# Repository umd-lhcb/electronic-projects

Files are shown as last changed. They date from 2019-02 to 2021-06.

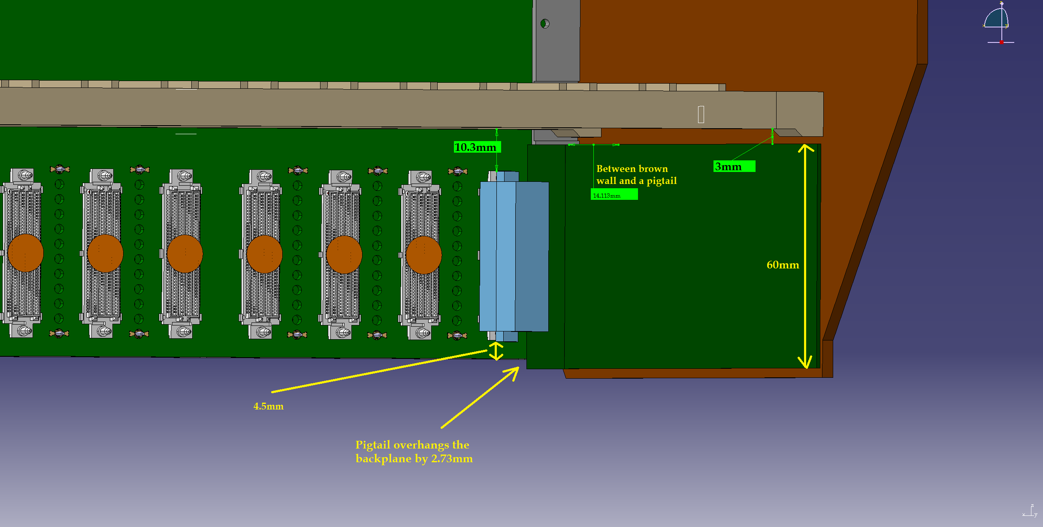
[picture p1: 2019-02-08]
backplane/mechanics/19-02-08_stackup_mech_constraints_cern/mech_constraints_backplane/BB_lower_DCB_GuideDetail__870a.png

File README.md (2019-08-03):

# electronic-projects
Repository with the project, gerber, and pdf files for the boards to
be delivered by UMD for the UT upgrade: `backplane`, `dcb`, and `lvr`.

Electronic boards designed by UMD for UT boards testing purposes, such as
`comet` and `gbtx_db`  are also included.

Latest pdf schematics of each project are also provided.

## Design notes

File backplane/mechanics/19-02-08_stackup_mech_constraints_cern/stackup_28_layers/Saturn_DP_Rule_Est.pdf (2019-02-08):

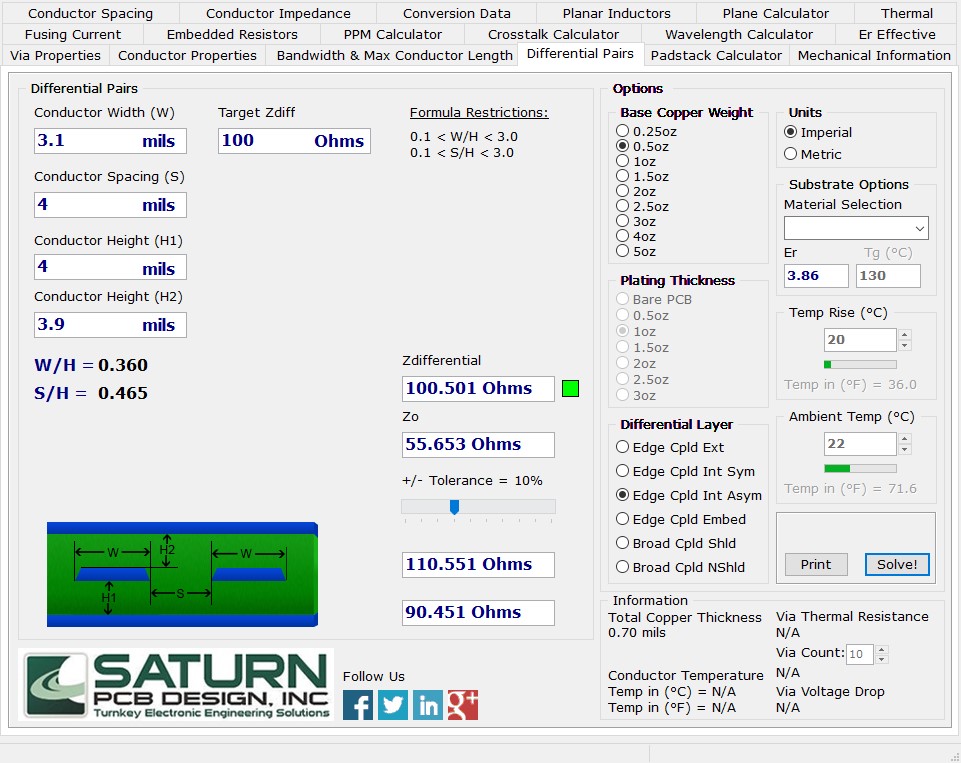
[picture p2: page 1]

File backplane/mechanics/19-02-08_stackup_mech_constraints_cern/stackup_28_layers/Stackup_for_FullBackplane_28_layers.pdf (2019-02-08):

| | | PathFinder-Alternate-28 layer
~ MILS | Cu layer
2 | 1 | Cu | | TOP plane--BROKEN Cu FILL
3.9 PP
0.7 | 2 | Cu | | DP signals-100 Ohms
4 CORE
0.7 | 3 | Cu | | plane
3.9 PP
0.7 | 4 | Cu | | DP signals-100 Ohms
4 CORE
0.7 | 5 | Cu | | plane
3.9 PP
0.7 | 6 | Cu | | DP signals-100 Ohms
4 CORE
0.7 | 7 | Cu | | plane
3.9 PP
0.7 | 8 | Cu | | DP signals-100 Ohms
4 CORE
0.7 | 9 | Cu | | plane
3.9 PP
0.7 | 10 | Cu | | DP signals-100 Ohms
4 CORE
0.7 | 11 | Cu | | plane
3.9 PP
0.7 | 12 | Cu | | SE.DP & NON-DP signal | Routing Constaints needed to control crosstalk & Tline discontinuities
4 CORE
0.7 | 13 | Cu | | SE.DP & NON-DP signal | Routing Constaints needed to control crosstalk & Tline discontinuities
3.9 PP
1.4 | 14 | Cu | 1OZ PWR- 1.2 & 1.5 | sub-divided power plane

### 2 CORE

1.4 | 15 | Cu | 1OZ PWR- 1.2 & 23.5 | sub-divided power plane
3.9 PP
0.7 | 16 | Cu | SE.DP & NON-DP signal | Routing Constaints needed to control crosstalk & Tline discontinuities
4 CORE
0.7 | 17 | Cu | SE.DP & NON-DP signal | Routing Constaints needed to control crosstalk & Tline discontinuities
3.9 PP
0.7 | 18 | Cu | plane
4 CORE
0.7 | 19 | Cu | DP signals-100 Ohms
3.9 PP
0.7 | 20 | Cu | plane
4 CORE
0.7 | 21 | Cu | DP signals-100 Ohms
3.9 PP
0.7 | 22 | Cu | plane
4 CORE
0.7 | 23 | Cu | DP signals-100 Ohms
3.9 PP
0.7 | 24 | Cu | plane
4 CORE
0.7 | 25 | Cu | DP signals-100 Ohms
3.9 PP
0.7 | 26 | Cu | plane
4 CORE
0.7 | 27 | Cu | DP signals-100 Ohms
3.9 PP
2 | 28 | Cu | BOT plane--BROKEN Cu FILL

128.2 mils total

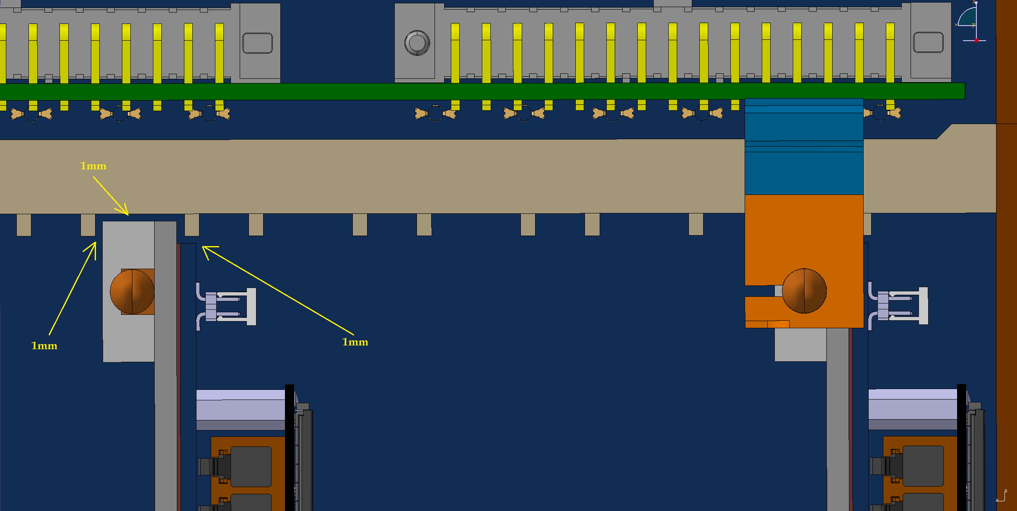
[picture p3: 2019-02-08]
backplane/mechanics/19-02-08_stackup_mech_constraints_cern/mech_constraints_backplane/BP_DCB_Slot_Detail__966.png

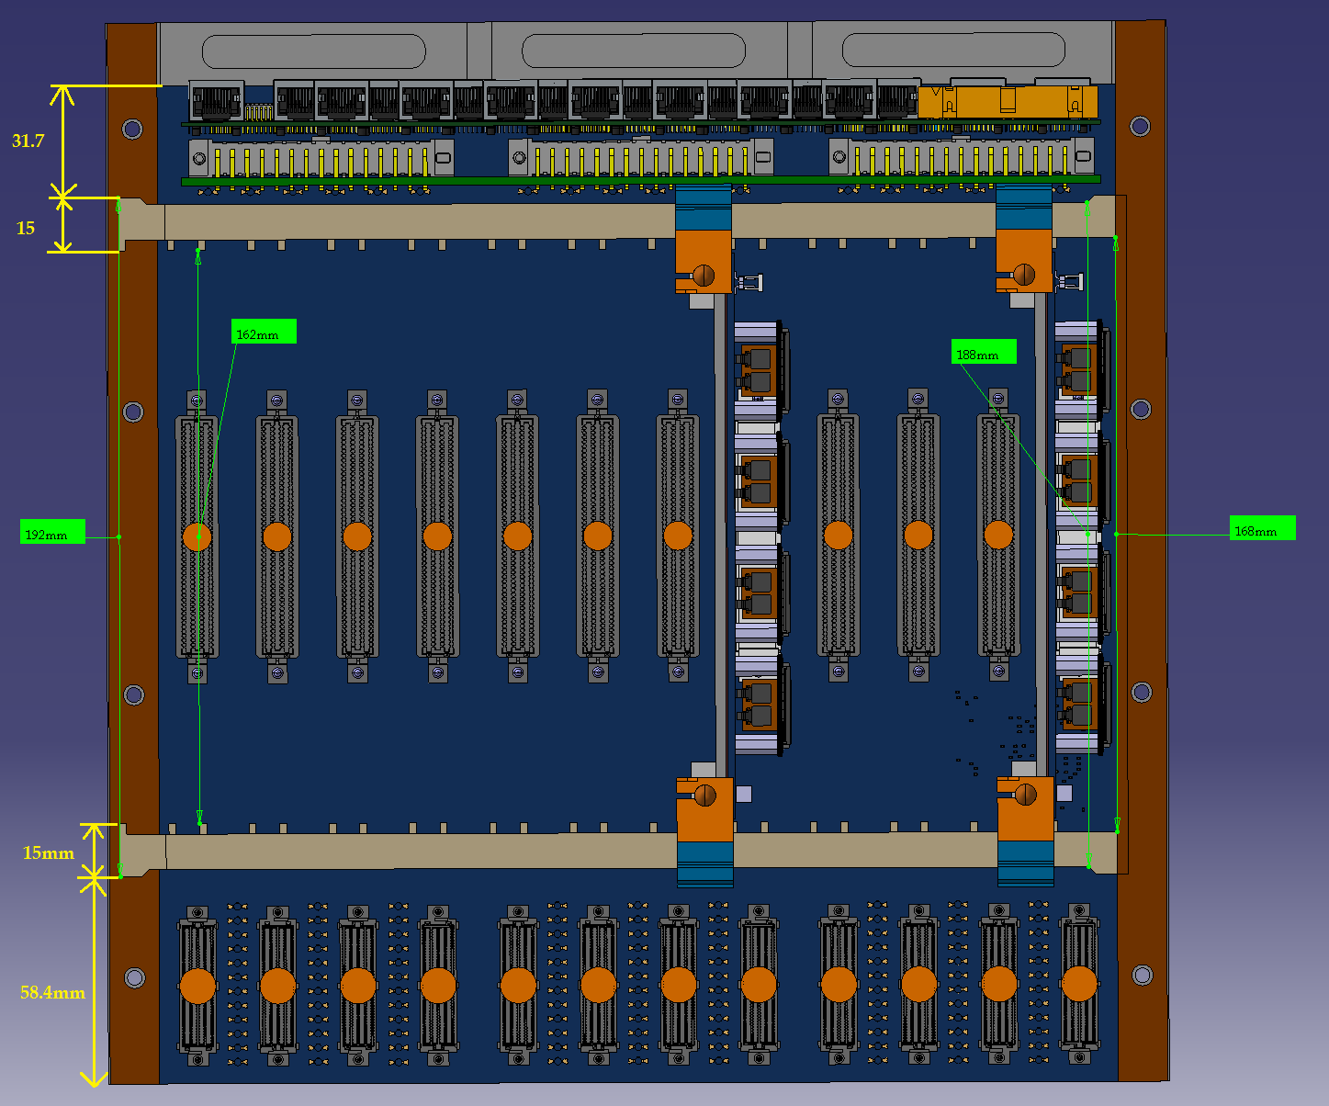
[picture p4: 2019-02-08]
backplane/mechanics/19-02-08_stackup_mech_constraints_cern/mech_constraints_backplane/BP_Conn_Location_Details__964.png

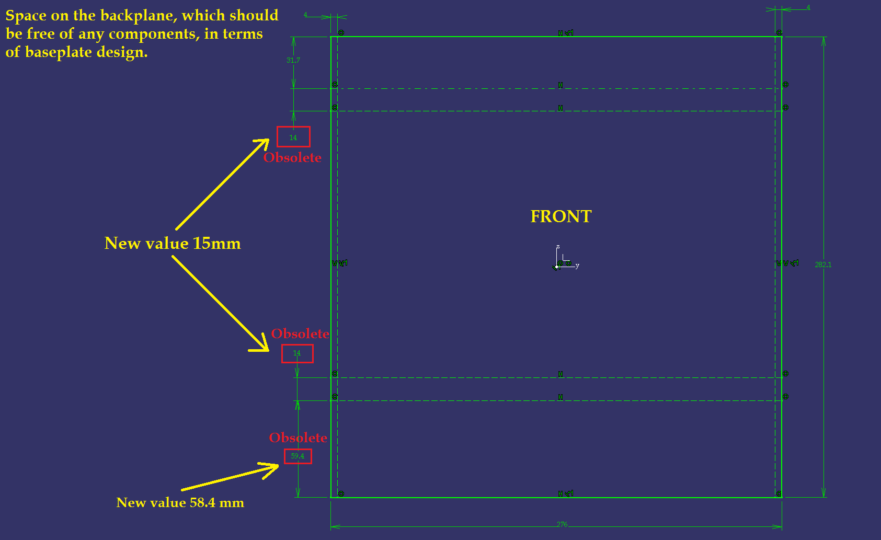
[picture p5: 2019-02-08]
backplane/mechanics/19-02-08_stackup_mech_constraints_cern/mech_constraints_backplane/BB_KeepOut__836c.png

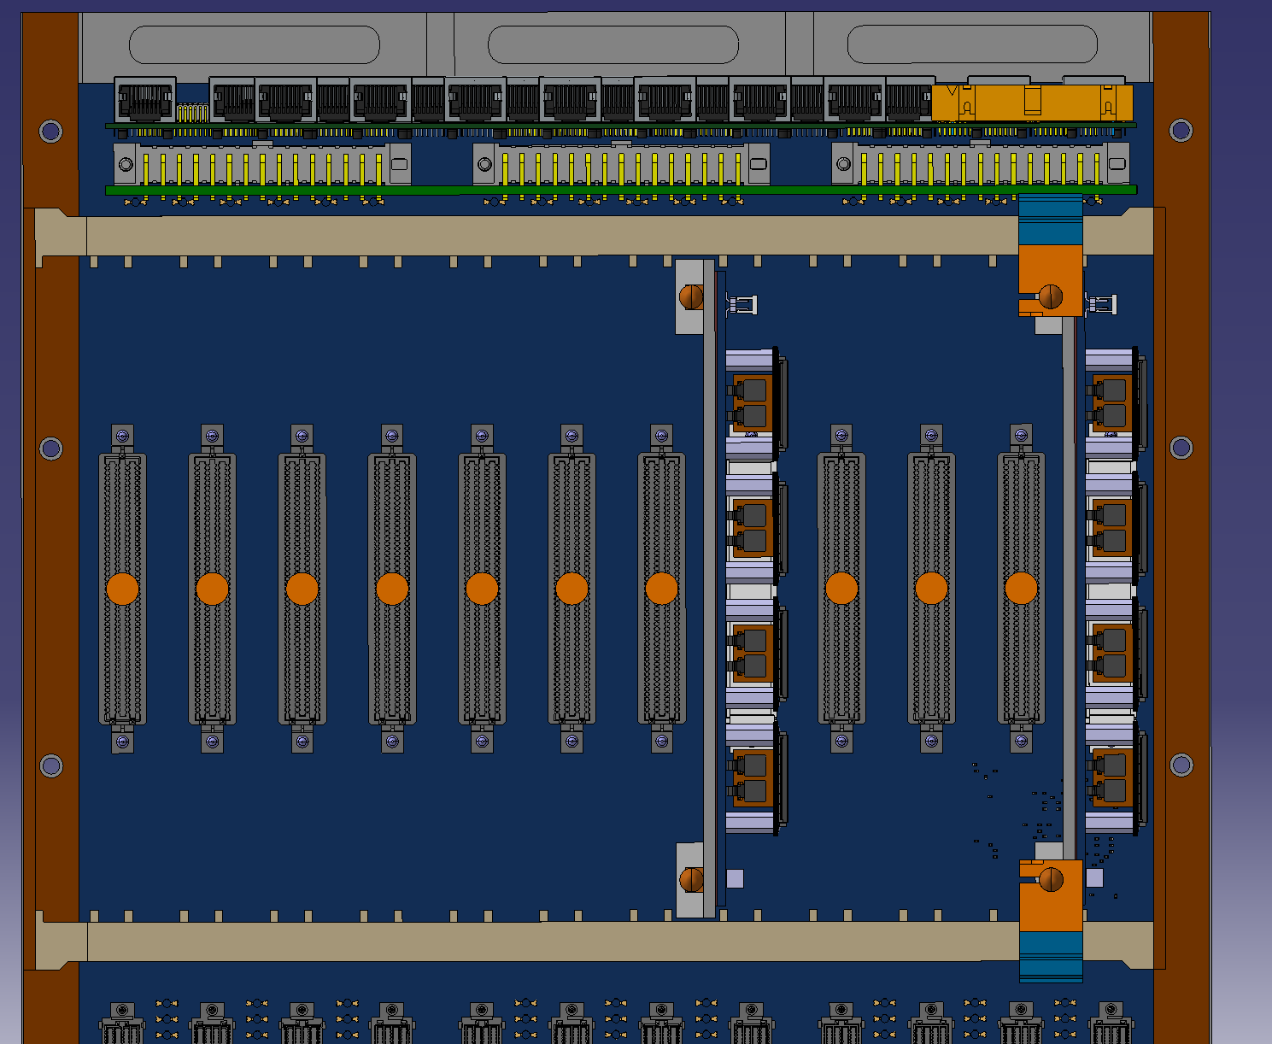
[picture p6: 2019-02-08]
backplane/mechanics/19-02-08_stackup_mech_constraints_cern/mech_constraints_backplane/BP_OverView__965.png

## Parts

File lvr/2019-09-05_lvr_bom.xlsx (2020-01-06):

Line ID | Designator | Quantity | Manufacturer | P/N | Description | Package | # Boards | Ext. Quant.
1 | C1 | 1 | Kemet | C0805C102K5RACTU | Non-polarised ceramic capacitor, X7R, 1.0nF, 50V, +/-10% tol | SMD 0805 | 295 | 325
2 | C2A, C2B, C2C, C2D, C2E, C2F, C2G, C2H, C100 | 9 | Yaego | CC0805JRNPO9BN100 | Non-polarised ceramic capacitor, NPO, 10pF, 50V, +/-5% tol | SMD 0805 | 295 | 2921
3 | C3A, C3B, C3C, C3D, C4, C5, C6, C7, C8, C9, C10, C11, C12, C15, C16, C27, C30, C34A, C34B, C34C, C34D, C34E, C34F, C34G, C34H, C47, C49, C58, C59, C60, C61, C62, C63, C66, C67, C69, C70, C72, C87, C88, C92, C95, C101, C141, C142, C143 | 46 | Murata | GCM155R71H103KA55D | Non-polarised ceramic capacitor, X7R, 0.01uF, 50V, +/-10% tol | SMD 0402 | 295 | 16963
4 | C13, C14, C21, C23, C38A, C38B, C38C, C38D, C38E, C38F, C38G, C38H, C39, C41A, C41B, C41C, C41D, C41E, C41F, C41G, C41H, C42A, C42B, C42C, C42D, C42E, C42F, C42G, C42H, C46, C64, C86, C93, C96, C98, C113, C114, C119, C122, C123A, C123B, C123C, C123D, C123E, C123F, C123G, C123H, C125A, C125B, C125C, C125D, C125E, C125F, C125G, C125H, C127A, C127B, C127C, C127D, C127E, C127F, C127G, C127H, C130, C132, C133, C134, C135, C144, C145 | 70 | Murata | GCM21BR71C475KA73K | Non-polarised ceramic capacitor, X7R, 4.7uF, 16V, +/-10% tol | SMD 0805 | 295 | 22715
5 | C17, C24A, C24B, C24C, C24D, C24E, C24F, C24G, C24H, C103, C147 | 11 | Kemet | C0805C105K4RACAUTO | Non-polarised ceramic capacitor, X7R, 1.0uF, 16V, +/-10% tol | SMD 0805 | 295 | 3570
6 | C18, C20, C22, C25A, C25B, C25C, C25D, C25E, C25F, C25G, C25H, C148 | 12 | AVX | TCJA106M016R0200 | Conductive Polymer Tantalum Capacitor, 16V, 200mOhm ESR, 10uF, +/-20% tol | SMD 1206 | 295 | 3894
7 | C19, C26, C28, C48, C31A, C31B, C31C, C31D, C31E, C31F, C31G, C31H, C52, C55, C65, C68, C71, C73, C89, C90, C97, C99, C102, C131, C146 | 25 | Yaego | CC0402KRX7R7BB104 | Non-polarised ceramic capacitor, X7R, 0.1uF, 16V, +/-10% tol | SMD 0402 | 295 | 9219
8 | C29, C33, C35 | 3 | AVX | 0402YC470KAT2A | Non-polarised ceramic capacitor, X7R, 47pF, 16V, +/-10% tol | SMD 0402 | 295 | 1107
9 | C32A, C32B, C32C, C32D, C32E, C32F, C32G, C32H, C80, C81, C82, C83, C84, C85, C104, C105 | 16 | AVX | TCJD227M016R0050 | Conductive Polymer Tantalum Capacitor, 16V, 50mOhm ESR, 220uF, +/-20% tol | SMD 2917 | 295 | 5192
10 | C56, C57, C74, C75, C76, C77, C78, C79, C126, C139, C140 | 11 | AVX | TCJD227M010R0050 | Conductive Polymer Tantalum Capacitor, 10V, 50mOhm ESR, 220uF, +/-20% tol | SMD 2917 | 295 | 3570
11 | C91, C94 | 2 | Yaego | CC0603KRX7R7BB334 | Non-polarised ceramic capacitor, X7R, 0.33uF, 16V, +/-10% tol | SMD 0603 | 295 | 620
12 | d8, d9, d10, d11, d12, d13, d14, d15, d16, d17, d19, D5, D6, D7 | 14 | On Semi | MBRS360BT3G | DIODE SCHOTTKY 60V 3A SMB | DO-214AA, SMB | 295 | 4337
13 | D2, D3A, D3B, D3C, D3D, D3E, D3F, D3G, D3H, D4A, D4B, D4C, D4D, D4E, D4F, D4G, D4H, D23, D24, D25 | 20 | Vishay Semi | VS-50WQ06FN-M3 | DIODE SCHOTTKY 60V 5.5A, TO-252AA | DO-252AA | 295 | 6490
14 | D18, D20A, D20B, D20C, D20D, D21A, D21B, D21C, D21D, D22A, D22B, D22C, D22D | 13 | On Semi | 1N4148WS | Diode general purpose, 75V, 150 ma | SOD323F | 295 | 4027
15 | IC1A, IC1B, IC1C, IC1D, IC1E, IC1F, IC1G, IC1H, IC2, IC6 | 10 | Maxim IC | MAX4238AUT+T | Op amp, rail-to-rail, 1MHz GBW, unit gain stable | SOT23-6 | 295 | 152
16 | IC4, IC7A, IC7B, IC7C, IC7D, IC7E, IC7F, IC7G, IC7H, IC15 | 10 | CERN | LHC4913PDU | 3A Positive Low Drop Adjustable Voltage Regulator With Inhibit Function | ST_POWERSO-20-SLUG-Up | 295 | 3098
17 | IC11 | 1 | Microsemi | A3PN250-VQG100 | ProASIC Nano FPGA, 250K gates, flash-based | 100-VQFP | 295 | 310
18 | IC12 | 1 | Maxim IC | MAX3491ESD+ | Differential Transceiver RS485/422, 10MBPS | 14SOIC | 295 | 310
19 | J1, J7, J8, J22 | 4 | Samtec | TMM-103-01-L-D-SM-P | Low profile SMT header, 2x3, 2mm pitch, 10um gold, Pick-N-Place Pad | SMD | 295 | 1239
20 | J4A, J4B, J4C, J4D, J4E, J4F, J4G, J4H | 8 | Samtec | SFM-115-02-L-D-A | Vertical 1.27mm pitch 2x15 connector, 10u-inch gold finish | SMD | 295 | 2478
21 | J5, J6, J10, J16 | 4 | Molex | 095540-6880 | RJ45 connector, shielded, right angle | SMD | 295 | 1239
22 | J11 | 1 | Samtec | TSM-115-01-S-DV-A-P | Contacts 2x15, Vertical, Surface Mount, Alignment Pins | SMD | 295 | 310
23 | J12, J13, J14 | 3 | Samtec | MPT-08-01-03-L-RA-SD | 30A power connector, 8 terminals, 10 u-inch gold finish | SMD | 295 | 930
24 | J15, J19, J20, J21 | 4 | Keystone | 4966 | Terminal lug, .250" X 0.032", right angle | Thru-hole | 295 | #N/A
25 | J17 | 1 | Samtec | HTST-105-04-G-D-RA | Shrouded header, 2x5 contacts, right angle, 10 u-inch gold finish | Thru-hole | 295 | #N/A
26 | J18 | 1 | Samtec | TSM-125-01-S-DV-A-P | vertical header pins, 2x25, 0.230 inch post height for mate with BCS | SMD | 295 | 310
27 | L1 | 1 | Murata | LQW31HN23NJ03L | 23nH Unshielded Wirewound Inductor, 590mA @ 46 mOhm Max | SMD 1206 / 3216 Metric | 295 | 325
28 | L2, L3 | 2 | Wurth | 742792022 | FERRITE BEAD 220 OHM @ 100 MHz | SMD 0805 | 295 | 649
29 | LD1, LD2, LD3, LD4, LD5, LD6, LD7 | 7 | Broadcom LTD (Avago) | HSME-C120 | LED GREEN CLEAR CHIP SMD R/A | SMD | 295 | 2272
30 | OSC1 | 1 | IQD Frq Products | LFSPXO018042REEL | Oscillator IQD_CFPS-73 (40MHz), 50 PPM freq Stab, 3.3V | 4-SMD | 295 | 310
31 | P1 | 1 | Bourns | 3223W-1-103E | Trimmer Pot, 11-turn, top Adj, 10K | SMD J-Lead | 295 | 310
32 | P2, P3, P4 | 3 | Bourns | 3223W-1-102E | Trimmer Pot, 11-turn, top Adj, 1K | SMD J-Lead | 295 | 930
33 | P5 | 1 | Bourns | 3223W-1-202E | Trimmer Pot, 11-turn, top Adj, 2K | SMD J-Lead | 295 | 310
34 | Q3A, Q3B, Q3C, Q3D | 4 | Diodes Inc | DMMT3906W-7-F | 40V MATCHED PAIR PNP SMALL SIGNAL TRANSISTOR | SMD SOT363 | 295 | 1298
35 | Q4, Q8A, Q8B, Q8C, Q8D, Q8E, Q8F, Q8G, Q8H | 9 | Diodes Inc | ZXT953K | Bipolar (BJT) Transistor PNP 100V 5A | SMD TO252 (DPAK) | 295 | 2788
36 | Q5, Q9A, Q9B, Q9C, Q9D, Q9E, Q9F, Q9G, Q9H | 9 | ON Semiconductor | PZT3904T1G | Bipolar (BJT) Transistor NPN 40V, 0.2A | SMD SOT-223 | 295 | 2788
37 | R1, R2, R3, R4, R94A, R94B, R94C, R94D, R94E, R94F, R94G, R94H, R102, R184, R212, R231A, R231B, R231C, R231D | 19 | Yageo | RC0402FR-0710KL | Resistor, 10K Ohms, +/-1% tol, 0.063 W | SMD 0402 | 295 | 7007
38 | R5, R44 | 2 | Vishay Dale | CRCW04021K00DHEDP | Resistor 1k Ohms, +/-1% tol, 0.063W, | SMD 0402 | 295 | 738
39 | R6A, R6B, R6C, R6D, R54, R62, R81A, R81B, R81C, R81D, R81E, R81F, R81G, R81H, R119, R127, R199 | 17 | Stackpole | RMCF0402FT2K00 | Resistor 2k Ohms, +/-1% tol, 0.063W, | SMD 0402 | 295 | 6269
40 | R125 | 0 | DNI | DNI | Do Not Install | SMD 0402 | 295 | 20
41 | R7, R8, R9, R36, R37, R50, R60, R71, R75, R77, R89, R99, R100, R117, R122, R123, R128, R129A, R129B, R129C, R129D, R130A, R130B, R130C, R130D, R131, R132, R177, R178, R180 | 30 | Yageo | RC0402FR-0733RL | Resistor, 33 Ohms, +/-1% tol, 0.063 W | SMD 0402 | 295 | 11063
42 | R10, R61A, R61B, R61C, R61D, R61E, R61F, R61G, R61H | 9 | vishay Dale | CRCW08055R10FKEAHP | Resistor 5.1 Ohms, +/-1% tol, 0.5W, pulse withstanding | SMD 0805 | 295 | 2921
43 | R11, R64, R65, R66, R88, R101, R107, R108, R109, R110, R111, R112, R115, R188 | 14 | TT Electronics (Welwyn) | LRC-LR2010LF-01-R500-F | Resistor 0.500 Ohms, +/-1% tol, 1.0W, | SMD 2010 | 295 | 4543
44 | R179, R209, R211 | 3 | Vishay Dale | CRCW0402100RFKED | Resistor 100 Ohms, +/-1% tol, 0.063W, | SMD 0402 | 295 | 1107
44 | R12, R13, R15, R16, R18, R19, R21, R22, R24, R25, R27, R28, R30, R31, R33, R34 | 16 | Stackpole | RMCF0402FT249R | Resistor 249 Ohms, +/-1% tol, 0.063W, | SMD 0402 | 295 | 5900
45 | R14, R17, R20, R23, R26, R29, R32, R35 | 8 | TT Electronics (Welwyn) | LRC-LRF2010LF-01-R020-F | Resistor 0.020 Ohms, +/-1% tol, 1.0W, current sense | SMD 2010 | 295 | 2596
46 | R38, R124 | 2 | Bourns | CRM0805-FX-R510ELF | Resistor 510 mOhms, +/-1%, 0.25W current sense | SMD 0805 | 295 | 649
47 | R40, R90A, R90B, R90C, R90D, R90E, R90F, R90G, R90H | 9 | Stackpole | CSRN2512FKR250 | Resistor 250 mOhms, +/-1%, 2W current sense | SMD 2512 | 295 | 2921
48 | R41, R92A, R92B, R92C, R92D, R92E, R92F, R92G, R92H | 9 | Yageo | RC0805FR-0749R9L | Resistor 49.9 Ohms, +/-1%, 0.125W | SMD 0805 | 295 | 2921
49 | R42 | 1 | Yageo | RC0402FR-07470RL | Resistor, 470 Ohms, +/-1% tol, 0.063 W | SMD 0402 | 295 | 369
50 | R43, R46, R48, R49, R58, R68, R74, R79, R84, R98A, R98B, R98C, R98D, R98E, R98F, R98G, R98H | 17 | Yageo | RC0805FR-07220RL | Resistor, 220 Ohms, +/-1% tol, 0.125 W | SMD 0805 | 295 | 5517
51 | R45, R70 | 2 | Yageo | RC0402FR-071K43L | Resistor 1k43 Ohms, +/-1% tol, 0.063W, | SMD 0402 | 295 | 738
52 | R47 | 0 | DNI | DNI | Do Not Install | SMD 0805 | 295 | 10
53 | R51, R76, R226A, R226B, R226C, R226D, R120, R126, R55A, R55B, R55C, R55D, R55E, R55F, R55G, R55H, R59A, R59B, R59C, R59D, R59E, R59F, R59G, R59H | 24 | Yageo | RC0402FR-071K2L | Resistor 1k2 Ohms, +/-1% tol, 0.063W, | SMD 0402 | 295 | 8850
54 | R52, R83 | 2 | Yageo | RC0402FR-07750RL | Resistor 750 Ohms, +/-1% tol, 0.063W, | SMD 0402 | 295 | 738
55 | R53 | 1 | Vishay Dale | CRCW08050000Z0EAHP | Resistor 0.0 Ohms Shunt Jumper | SMD 0805 | 295 | 325
56 | R56, R85 | 2 | Yageo | RC0402FR-076K2L | Resistor 6.2K Ohms, +/-1% tol, 0.063W, | SMD 0402 | 295 | 738
57 | R57, R82 | 0 | DNI | DNI | Do Not Install | SMD 0805 | 295 | 10
58 | R63A, R63B, R63C, R63D, R63E, R63F, R63G, R63H, R181, R182, R183 | 11 | Vishay Dale | CRCW0402510RFKED‎C | Resistor 510 Ohms, +/-1% tol, 0.063W, | SMD 0402 | 295 | 4057
59 | R67, R72 | 2 | Yageo | RC0402FR-07140RL | Resistor 140 Ohms, +/-1% tol, 0.063W, | SMD 0402 | 295 | 738
60 | R69, R113, R114, R210 | 4 | Yageo | RC0402FR-0749R9L | Resistor 49.9 Ohms, +/-1% tol, 0.063W, | SMD 0402 | 295 | 1475
61 | R73A, R73B, R73C, R73D, R73E, R73F, R73G, R73H | 8 | Stackpole | CSRN2010FK50L0 | Resistor, 50 mOhms, +/-1%, 1W | SMD 2010 | 295 | 2596
62 | R39, R78A, R78B, R78C, R78D, R78E, R78F, R78G, R78H | 9 | Bourns | CRM2512-FX-R100ELF | Resistor 100 mOhms, +/-1%, 2W current sense | SMD 2512 | 295 | 2921
63 | R80A, R80B, R80C, R80D, R208, R230A, R230B, R230C, R230D | 9 | yageo | RC0402FR-07200RL | Resistor 200 Ohms, +/-1% tol, 0.063W, | SMD 0402 | 295 | 3319
64 | R86 | 1 | yageo | RC0402FR-07249RL | Resistor 249 Ohms, +/-1% tol, 0.063W, | SMD 0402 | 295 | 369
65 | R87 | 1 | Stackpole | RMCF0402FT1K10 | Resistor1.1K Ohms, +/-1% tol, 0.063W, | SMD 0402 | 295 | 369
66 | R91A, R91B, R91C, R91D, R91E, R91F, R91G, R91H | 8 | Stackpole | CSRN2010FKR150 | Resistor 0.150 Ohms, +/-1% tol, 1.0W, | SMD 2010 | 295 | 2596
67 | R93A, R93B, R93C, R93D, R93E, R93F, R93G, R93H | 8 | yageo | RC0805FR-07470RL | Resistor 470 Ohms, +/-1%, 0.125W | SMD 0805 | 295 | 2596
68 | R95, R97 | 2 | yageo | RC0805FR-07360RL | Resistor 360 Ohms, +/-1%, 0.125W | SMD 0805 | 295 | 649
69 | R96 | 1 | yageo | RC0805FR-07121RL | Resistor 121 Ohms, +/-1%, 0.125W | SMD 0805 | 295 | 325
70 | R103, R104, R105, R106, R121 | 5 | yageo | RC0603FR-07360RL | Resistor 360 Ohms, +/-1%, 0.1W | SMD 0603 | 295 | 1697
71 | R116, R227A, R227B, R227C, R227D | 5 | Panasonic | ERJ-2RKF4871X | Resistor 4.87K Ohms, +/-1%, 0.1W | SMD 0402 | 295 | 1844
72 | R118 | 1 | Yageo | RC0805FR-076K2L | Resistor 6.2K Ohms, +/-1%, 0.125W | SMD 0805 | 295 | 325
73 | R161A, R161B, R161C, R161D, R161E, R161F, R161G, R161H, R203A, R203B, R203C, R203D, R203E, R203F, R203G, R203H | 16 | Yageo | RC0402FR-0751KL | Resistor 51K Ohms, +/-1% tol, 0.063W, | SMD 0402 | 295 | 5900
74 | R207, R229A, R229B, R229C, R229D | 5 | Yageo | RC0402FR-07390RL | Resistor 390 Ohms, +/-1% tol, 0.063W, | SMD 0402 | 295 | 1844
75 | R225A, R225B, R225C, R225D | 4 | Yageo | RC0402FR-07560RL | Resistor 560 Ohms, +/-1% tol, 0.063W, | SMD 0402 | 295 | 1475
76 | R228A, R228B, R228C, R228D | 4 | Yageo | RC0402FR-07820RL | Resistor 820 Ohms, +/-1% tol, 0.063W, | SMD 0402 | 295 | 1475
77 | RN1A, RN1B, RN1C, RN1D, RN1E, RN1F, RN1G, RN1H, RN3A, RN3B, RN3C, RN3D, RN3E, RN3F, RN3G, RN3H | 16 | Vishay Beyschlag | ACASA2001X2001P100 | WHERE 'X'=S, 1, T, or U (in this order of preference). Resistor network, 2k Ohm x4, TC and tol. Specified by 'X' | SMD 0612 | 295 | 5192
78 | RN2A, RN2B, RN2C, RN2D, RN2E, RN2F, RN2G, RN2H | 8 | Vishay Beyschlag | ACASA5002X5002P100 | WHERE 'X'=S, 1, T, or U (in this order of preference). Resistor network, 51k Ohm x4, TC and tol. Specified by 'X' | SMD 0612 | 295 | 2596
79 | RN6 | 1 | Vishay Beyschlag | ACASA1001X1001P100 | WHERE 'X'=S, 1, T, or U (in this order of preference). Resistor network, 1k Ohm x4, TC and tol. Specified by 'X' | SMD 0612 | 295 | 325
80 | RN7 | 1 | Vishay Beyschlag | ACASA1000X1000P100 | WHERE 'X'=S, 1, T, or U (in this order of preference). Resistor network, 100 Ohm x4, TC and tol. Specified by 'X' | SMD 0612 | 295 | 325
81 | RN8 | 1 | Vishay Beyschlag | ACASA1002X1002P100 | WHERE 'X'=S, 1, T, or U (in this order of preference). Resistor network, 10K Ohm x4, TC and tol. Specified by 'X' | SMD 0612 | 295 | 325
82 | RN9, RN10, RN17, RN18, RN19, RN20, RN21, RN22, RN23, RN24 | 10 | Panasonic | EXB-N8V103JX | 4 Resistor Network/Array, 10k Ohm Isolated, ±5%, 31mW Power Per Element, ±200ppm/°C , Concave, Long Side Terminals | SMD 0804 | 295 | 3393
83 | RN11, RN12, RN13, RN14, RN15, RN16, RN25, RN26, RN27, RN28 | 10 | Panasonic | EXB-N8V330JX | 4 Resistor Network/Array, 33 Ohm Isolated, ±5%, 31mW Power Per Element, ±200ppm/°C , Concave, Long Side Terminals | SMD 0804 | 295 | 3393
84 | RT1, RT2, RT3 | 3 | TE Connectivity, Meas't Specialities | NB-PTCO-330 | 1 kOhms RTD, ±0.23%, -50°C ~ 150°C, 1206 (3216 Metric) | SMD 1206 | 295 | 974
85 | RT4A, RT4B, RT4C, RT4D | 4 | TDK (EPCOS) | B57471V2472J062 | 4.7K thermistor, NTC, 5% tol | SMD 0805 | 295 | 1239
86 | SW1, SW2, SW3, SW4, SW5, SW6A, SW6B, SW6C, SW6D | 9 | Nidec Copal Electronics | CHS-04TA | Dip Switch SPST 4 Position Surface Mount Slide (Standard) Actuator 100mA 6VDC | SMD J-lead | 295 | 2921
87 | T1A, T1B, T1C, T1D, T1E, T1F, T1G, T1H, T2A, T2B, T2C, T2D, T3 | 13 | ON Semiconductor | MMBT3904WT1G | Bipolar (BJT) Transistor NPN 40V 200mA 300MHz 150mW | SMD SC-70-3 (SOT323) | 295 | 4027
88 | TP1, TP2A, TP2B, TP2C, TP2D, TP2E, TP2F, TP2G, TP2H, TP3, TP4, TP5A, TP5B, TP5C, TP5D, TP5E, TP5F, TP5G, TP5H, TP6, TP7, TP8, TP9, TP10, TP11A, TP11B, TP11C, TP11D, TP11E, TP11F, TP11G, TP11H, TP12, TP13, TP14, TP15, TP16, TP17, TP18A, TP18B, TP18C, TP18D, TP19A, TP19B, TP19C, TP19D, TP20, TP21 | 48 | Tyco | RCT-0C | PCB test point | SMD
Misc HW
1 | WL1, WL2 | 2
2 | M3 retention hardware for J12, J13, and J14 | 3 conns
3 | 2mm Shunt Jumpers |  | Samtec | 2SN–BK–G | 2mm pitch shunt for use with TMM series, gold sockets
4 | P4A, P4B, P4C, P4D, P4E, P4F, P4G, P4H |  | UMD | CCM-TypeID | Config Control Mezzanine
 |  |  |  | Component | % extra | min extra
 |  |  |  | SMD 0201 | 0.5 | 50
 |  |  |  | SMD 0402 | 0.25 | 20
 |  |  |  | SMD 0603 | 0.15 | 20
 |  |  |  | SMD 0804 | 0.15 | 20
 |  | 754 |  | SMD 0805 | 0.1 | 10
 |  |  |  | SMD 1206 | 0.1 | 5
 |  |  |  | SMD 0612 | 0.1 | 5
 |  |  |  | SMD 2010 | 0.1 | 5
 |  |  |  | SMD 2512 | 0.1 | 5
 |  |  |  | SMD 2917 | 0.1 | 5
 |  |  |  | Other Passive | 0.1 | 5
 |  |  |  | Thru-Hole | 0.02 | 1

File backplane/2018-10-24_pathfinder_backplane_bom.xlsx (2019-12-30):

Line Item | Designator | LibRef | Qty | Chk | PartNumID | Manufacturer | P/N | Description | Package
1 | C49, C50, C51, C52, C53, C54, C55, C56, C57, C58, C59, C60, C61, C62, C63, C64, C65, C66, C67, C68, C69, C70, C71, C72, C73, C74, C75, C76, C77, C78, C79, C80, C81, C82, C83, C84, C85, C86, C87, C88, C89, C90, C91, C92, C93, C94, C95, C96, C97, C98, C99, C100, C101, C102, C103, C212, C213, C214, C215, C216, C217, C218, C219, C220, C221, C222, C223, C224, C225, C226, C227, C228, C229, C230, C231, C232, C233, C234, C235, C236, C237, C238, C239, C240, C241, C242, C243 |  | 87 |  | cap10 | Samsung Electro-Mechanics | CL05B473KO5VPNC | Non-polarised ceramic capacitor, X7R, 0.047uF, 16V, +/-10% tol | SMD 0402
2 | C1, C2, C3, C4, C5, C6, C7, C8, C9, C10, C11, C12, C13, C14, C15, C16, C17, C18, C19, C20, C21, C22, C23, C24, C25, C26, C27, C28, C29, C30, C31, C32, C33, C34, C35, C36, C37, C38, C39, C40, C41, C42, C43, C44, C45, C46, C47, C48 |  | 48 |  | cap11 | Murata | GCM155R71E103KA37D | Non-polarised ceramic capacitor, X7R, 0.01uF, 25V, +/-10% tol | SMD 0402
3 | C104, C105, C106, C107, C108, C109, C110, C111, C112, C113, C114, C115, C116, C117, C118, C119, C120, C121, C122, C123, C124, C125, C126, C127, C128, C129, C130, C131, C132, C133, C134, C135, C136, C137, C138, C139, C140, C141, C142, C143, C144, C145, C146, C147, C148, C149, C150, C151, C152, C153, C154, C155, C156, C157, C158, C159, C160, C161, C162, C163, C164, C165, C166, C167, C168, C169, C170, C171, C172, C173, C174, C175, C176, C177, C178, C179, C180, C181, C182, C183, C184, C185, C186, C187, C188, C189, C190, C191, C192, C193, C194, C195, C196, C197, C198, C199, C200, C201, C202, C203, C204, C205, C206, C207, C208, C209, C210, C211 |  | 108 |  | cap2 | Murata | GRM155R71C104KA88 | Non-polarised ceramic capacitor, X7R, 0.1uF, 16V, +/-10% tol | SMD 0402
4 | COMET_A_J1, COMET_A_J2, COMET_B_J1, COMET_B_J2 |  | 4 |  | conn20 | Samtec | ERF8-050-05.0-S-DV-K-TR | Connector, 2 x50, -05.0 lead style, 30u gold, | SMD
5 | J38, J52 |  | 2 |  | conn3 | Samtec | TMM-110-01-L-D-SM-A-P | Low profile SMT header, 2x10, 2mm pitch, 10um gold, SMD alignment pin, Pick-N-Place Pad | SMD
6 | J39, J53 |  | 2 |  | conn4 | Samtec | TMM-112-01-L-D-SM-A-P | Low profile SMT header, 2x12, 2mm pitch, 10um gold, SMD alignment pin, Pick-N-Place Pad | SMD
7 | J1, J2, J3, J4, J5, J6, J7, J8, J9, J10, J11, J12, J13, J14, J15, J16, J17, J18, J19, J20, J21, J22, J23, J24, J25, J26, J27, J28, J29, J30, J31, J32, J33, J34, J35, J36, J37, J40, J41, J42, J43, J44, J45, J46, J47, J48, J49, J50, J51, J54, J55, J56, J57, J58, J59, J60 |  | 56 |  | conn1 | Hirose | U.FL-R-SMT-1(10) | U.FL, Ultra Miniature Coaxial Connector Receptacle, Male Pin 50 Ohm Surface Mount Solder | SMD
8 | JP0, JP1, JP2, JP3, JP4, JP5, JP6, JP7, JP8, JP9, JP10, JP11 |  | 12 |  | Conn15 | Samtec | SEAM8-40-S02.0-S-10-2-GP-K | SEARAY 0.8 mm pitch connector, 40x10, 2mm body height, Vertical, guide posts | SMD
9 | JD0, JD1, JD2, JD3, JD4, JD5, JD6, JD7, JD8, JD9, JD10, JD11 |  | 12 |  | Conn16 | Samtec | SEAM-50-02.0-S-08-2-A-GP-K-TR | SEARAY 1.25 mm pitch connector, 50x8, 2mm body height, Vertical, guide posts | SMD
10 | JPL0, JPL1, JPL2 |  | 3 |  | Conn17 | Samtec | IPBS-115-01-T-D-GP | PowerMate, 15 x 2 sockets, thru hole, Mate Tin, Double row, Guide posts | ThruHole
11 | JT0, JT1, JT2 |  | 3 |  | Conn18 | Samtec | SMS-150-02-L-D | Thru-hole micro sockets, 2x50, gold on contact + tin on tail, double row | ThruHole
12 | JS_JPU_ZERO_1 thru JS_JPU_ZERO_30 'JS_JPU_ONE_1 thru JS_JPU_ONE_30 'JS_JPU_TWO_1 thru JS_JPU_TWO_30 JS_PT_ZERO_ONE_1, JS_PT_ZERO_ONE_2, JS_PT_ONE_TWO_1, JS_PT_ONE_TWO_2, JS_PT_TWO_THREE_1, JS_PT_TWO_THREE_2, JS_JPL_ZERO_1 Thru JS_JPL_ZERO_6, JS_PT_FOUR_FIVE_1, JS_PT_FOUR_FIVE_2, JS_PT_FIVE_SIX_1, JS_PT_FIVE_SIX_2, JS_PT_SIX_SEVEN_1, JS_PT_SIX_SEVEN_2, JS_JPL_ONE_1 Thru JS_JPL_ONE_6, JS_PT_EIGHT_NINE_1, JS_PT_EIGHT_NINE_2, JS_PT_NINE_TEN_1, JS_PT_NINE_TEN_2, JS_PT_TEN_ELEVEN_1, JS_PT_TEN_ELEVEN_2, JS_JPL_TWO_1 Thru JS_JPL_TWO_6 |  | 126 |  | Conn19 | cap11+U8+U2+U3 | S9121-45R | Harwin Bottom entry sycamore socket, surface mount | SMD / Thru-hole
13 | R1, R2, R3, R4, R5, R6, R7, R8, R9, R10, R11, R12, R13, R14, R81, R87, R222, R223, R224, R225, R226, R227, R228, R229, R230, R231, R232, R233, R234, R235, R236, R237, R238, R239, R240, R241, R242, R243, R244, R245, R246, R247, R248, R249, R250, R251, R252, R253, R254, R255, R256, R257, R258, R259 |  | 54 |  | RES15 | Rohm Semiconductor | ESR10EZPJ5R6 | Resistor 5.6 Ohms, +/-5% tol, 0.4W, | SMD 0805
 | R15, R16, R17, R18, R19, R20, R21, R22, R23, R24, R25, R26, R27, R28, R29, R30, R31, R32, R33, R34, R35, R36, R37, R38, R39, R40, R41, R42, R43, R44, R45, R46, R47, R48, R49, R50, R51, R52, R53, R54, R55, R56, R57, R58, R59, R60, R61, R62, R63, R64, R65, R66, R67, R68, R69, R70, R71, R72, R73, R74, R75, R76, R77, R78, R79, R80, R82, R83, R84, R85, R86, R88, R89, R90, R91, R92, R93, R94, R95, R96, R97, R98, R99, R100, R101, R102, R103, R104, R105, R106, R107, R108, R109, R110, R111, R112, R113, R114, R115, R116, R117, R118, R119, R120, R121, R122, R123, R124, R125, R126, R127, R128, R129, R130, R131, R132, R133, R134, R135, R136, R137, R138, R139, R140, R141, R142, R143, R144, R145, R146, R147, R148, R149, R150, R151, R152, R153, R154, R155, R156, R157, R158, R159, R160, R161, R162, R163, R164, R165, R166, R167, R168, R169, R170, R171, R172, R173, R174, R175, R176, R177, R178, R179, R180, R181, R182, R183, R184, R185, R186, R187, R188, R189, R190, R191, R192, R193, R194, R195, R196, R197, R198, R199, R200, R201, R202, R203, R204, R205, R206, R207, R208, R209, R210, R211, R212, R213, R214, R215, R216, R217, R218, R219, R220, R221 |  | 205 |  |  |  |  | Do Not Install (100 Ohms, 040 package) | SMD 0402
14 | RT1 |  | 1 |  | RTD1 | TE Connectivity, Meas't Specialities | NB-PTCO-330 | 1 kOhms RTD, ±0.23%, -50°C ~ 150°C, 1206 (3216 Metric) | SMD 1206

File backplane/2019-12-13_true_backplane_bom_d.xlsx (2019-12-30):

Designator | MFG P/N | Package | Outline | PopulationType | DeviceType | Value | Quantity | Supplier | Description
FTG1, FTG2, FTG3, FTG4, FTG5, FTG6 | FIDUCIAL_TARGET_C100-200 | FIDUCIAL_TOP_C100-200 | - | MECH | DNI | - | 6 |  | Fiducial Target
C1, C2, C3, C4, C5, C6, C7, C9, C12, C14, C15, C20, C21, C22, C23, C24, C25, C26, C27, C34, C36, C37, C38, C39, C40, C41, C42, C44, C51, C52, C57, C60, C65, C68, C74, C75, C82, C84, C85, C87, C92, C99, C102, C104, C105, C106, C107, C108, C109, C110, C112, C115, C117, C118, C124, C129, C131, C132, C133, C134, C135, C136, C137, C138, C139, C140, C141, C142, C144, C145, C146, C151, C158, C160, C161, C162, C163, C164, C165, C166, C168, C170, C171, C177, C182, C184, C185, C186, C187, C188, C189, C190, C191, C192, C193, C194, C195, C196, C198, C199, C200, C202, C203, C207, C214, C217, C219, C220, C221, C222, C223, C224, C225, C227, C230, C232, C233, C239, C243, C244, C245, C246, C247, C248, C249, C250, C251, C252, C253, C254, C255, C256, C257, C258, C259, C263, C270, C272, C273, C274, C275, C276, C277, C278, C279, C280, C281, C282, C283, C284, C285, C286, C287, C288, C290, C297, C298, C302, C303, C304, C305, C306, C307, C308, C309, C310, C311, C312, C313, C314, C315, C316, C317, C318, C319, C320, C324, C327, C332, C335 | CC0402KRX7R7BB473 | CAPC1005X55N | 402 | SMD | SMD | 47nF | 180 | Customer will provide | Non-polarised capacitor
C8, C10, C11, C13, C16, C18, C19, C28, C32, C33, C35, C43, C45, C46, C47, C49, C53, C56, C58, C59, C61, C62, C63, C64, C66, C67, C69, C71, C73, C77, C79, C80, C81, C83, C86, C88, C89, C93, C94, C96, C98, C100, C101, C103, C111, C113, C114, C116, C120, C122, C123, C127, C128, C130, C143, C147, C148, C152, C153, C155, C157, C159, C167, C169, C173, C175, C176, C180, C181, C183, C197, C201, C204, C208, C209, C212, C213, C215, C216, C218, C226, C228, C229, C231, C235, C237, C238, C242, C260, C264, C265, C268, C269, C271, C289, C291, C293, C295, C296, C301, C321, C325, C326, C329, C331, C333, C334, C336 | EMK105B7104KV-F | CAPC1005X55N | 402 | SMD | SMD | 100nF | 108 | Customer will provide | Non-polarised capacitor
C17, C29, C30, C31, C48, C50, C54, C55, C70, C72, C76, C78, C90, C91, C95, C97, C119, C121, C125, C126, C149, C150, C154, C156, C172, C174, C178, C179, C205, C206, C210, C211, C234, C236, C240, C241, C261, C262, C266, C267, C292, C294, C299, C300, C322, C323, C328, C330 | TMK105B7103KV-F | CAPC1005X55N | 402 | SMD | SMD | 10nF | 48 | Customer will provide | Non-polarised capacitor
CxRB_1, CxRB_2, CxRB_3, CxRB_4, CxRB_5, CxRB_6, CxRB_7, CxRB_8, CxRB_9, CxRB_10, CxRB_11, CxRB_12, CxRB_13, CxRB_14, CxRB_15, CxRB_16, CxRB_17, CxRB_18, CxRB_19, CxRB_20, CxRB_21, CxRB_22, CxRB_23, CxRB_24, CxRB_25, CxRB_26, CxRB_27, CxRB_28, CxRB_29, CxRB_30, CxRB_31, CxRB_32, CxRB_33, CxRB_34, CxRB_35, CxRB_36 | RK73H1ETTP1000F | RESC1005X40N | 402 | SMD | SMD | 100 | 36 | Customer will provide | Resistor - 1%
R1, R2, R9, R10, R11, R12, R17, R18, R19, R20, R21, R23, R24, R29, R30, R33, R34, R35, R40, R45, R48, R49, R50, R55, R56, R59, R60, R61, R66, R67, R68, R74, R75, R78, R79, R80, R83, R86, R89, R90, R91, R96, R97, R100, R105, R106, R109, R115, R116, R117, R118, R123, R124, R125 | RC0805FR-075R6L | RESC2012X60N | 805 | SMD | SMD | 5R6 | 54 | Customer will provide | Resistor - 2%
R3, R4, R5, R6, R7, R8, R13, R14, R15, R16, R22, R25, R26, R27, R28, R31, R32, R36, R37, R38, R39, R41, R42, R43, R44, R46, R47, R51, R52, R53, R54, R57, R58, R62, R63, R64, R65, R69, R70, R71, R72, R73, R76, R77, R81, R82, R84, R85, R87, R88, R92, R93, R94, R95, R98, R99, R101, R102, R103, R104, R107, R108, R110, R111, R112, R113, R114, R119, R120, R121, R122 | RK73H1ETTP1000F | RESC1005X40N | 402 | SMD | SMD | 100 | 71 | Customer will provide | Resistor - 1%
RB_1, RB_2, RB_3, RB_4, RB_5, RB_6, RB_7, RB_8, RB_9, RB_10, RB_11, RB_12, RB_13, RB_14, RB_15, RB_16, RB_17, RB_18, RB_19, RB_20, RB_21, RB_22, RB_23, RB_24, RB_25, RB_26, RB_27, RB_28, RB_29, RB_30, RB_31, RB_32, RB_33, RB_34, RB_35, RB_36, RB_37, RB_38, RB_39, RB_40, RB_41, RB_42, RB_43, RB_44, RB_45, RB_46, RB_47, RB_48, RB_49, RB_50, RB_51, RB_52, RB_53, RB_54, RB_55, RB_56, RB_57, RB_58, RB_59, RB_60, RB_61, RB_62, RB_63, RB_64, RB_65, RB_66, RB_67, RB_68, RB_69, RB_70, RB_71, RB_72, RB_73, RB_74, RB_75, RB_76, RB_77, RB_78, RB_79, RB_80, RB_81, RB_82, RB_83, RB_84, RB_85, RB_86, RB_87, RB_88, RB_89, RB_90, RB_91, RB_92, RB_93, RB_94, RB_95, RB_96, RB_97, RB_98, RB_99, RB_100, RB_101, RB_102, RB_103, RB_104, RB_105, RB_106, RB_107, RB_108, RB_109, RB_110, RB_111, RB_112, RB_113, RB_114, RB_115, RB_116, RB_117, RB_118, RB_119, RB_120, RB_121, RB_122, RB_123, RB_124, RB_125, RB_126, RB_127, RB_128, RB_129, RB_130, RB_131, RB_132, RB_133, RB_134, RB_135, RB_136, RB_137, RB_138, RB_139, RB_140, RB_141, RB_142, RB_143, RB_144, RB_145, RB_146, RB_147, RB_148, RB_149, RB_150, RB_151, RB_152, RB_153, RB_154, RB_155, RB_156, RB_157, RB_158, RB_159, RB_160, RB_161, RB_162, RB_163, RB_164, RB_165, RB_166, RB_167, RB_168, RB_169, RB_170, RB_171, RB_172, RB_173, RB_174, RB_175, RB_176, RB_177, RB_178, RB_179, RB_180, RB_181, RB_182, RB_183, RB_184, RB_185, RB_186, RB_187, RB_188, RB_189, RB_190, RB_191, RB_192, RB_193, RB_194, RB_195, RB_196, RB_197, RB_198, RB_199, RB_200, RB_201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 | RK73H1ETTP1000F | RESC1005X40N | 402 | SMD | SMD | 100 | 595 | Customer will provide | Resistor - 1%
RBSP_1, RBSP_2, RBSP_3, RBSP_4, RBSP_5, RBSP_6, RBSP_7, RBSP_8, RBSP_9, RBSP_10, RBSP_11, RBSP_12, RBSP_13, RBSP_14, RBSP_15, RBSP_16, RBSP_17, RBSP_18, RBSP_19, RBSP_20, RBSP_21, RBSP_22, RBSP_23, RBSP_24, RBSP_25, RBSP_26, RBSP_27, RBSP_28, RBSP_29, RBSP_30, RBSP_31, RBSP_32, RBSP_33, RBSP_34, RBSP_35, RBSP_36, RBSP_37, RBSP_38, RBSP_39, RBSP_40, RBSP_41, RBSP_42, RBSP_43, RBSP_44, RBSP_45, RBSP_46, RBSP_47, RBSP_48, RBSP_49, RBSP_50, RBSP_51, RBSP_52, RBSP_53, RBSP_54, RBSP_55, RBSP_56, RBSP_57, RBSP_58, RBSP_59, RBSP_60, RBSP_61, RBSP_62, RBSP_63, RBSP_64, RBSP_65, RBSP_66, RBSP_67, RBSP_68, RBSP_69, RBSP_70, RBSP_71, RBSP_72, RBSP_73, RBSP_74, RBSP_75, RBSP_76, RBSP_77, RBSP_78, RBSP_79, RBSP_80, RBSP_81, RBSP_82, RBSP_83, RBSP_84, RBSP_85, RBSP_86, RBSP_87, RBSP_88, RBSP_89, RBSP_90, RBSP_91, RBSP_92, RBSP_93, RBSP_94, RBSP_95, RBSP_96, RBSP_97, RBSP_98, RBSP_99, RBSP_100, RBSP_101, RBSP_102, RBSP_103, RBSP_104, RBSP_105, RBSP_106, RBSP_107, RBSP_108, RBSP_109, RBSP_110, RBSP_111, RBSP_112, RBSP_113, RBSP_114, RBSP_115, RBSP_116, RBSP_117, RBSP_118, RBSP_119, RBSP_120, RBSP_121, RBSP_122, RBSP_123, RBSP_124, RBSP_125, RBSP_126, RBSP_127, RBSP_128, RBSP_129, RBSP_130, RBSP_131, RBSP_132, RBSP_133, RBSP_134, RBSP_135, RBSP_136, RBSP_137, RBSP_138, RBSP_139, RBSP_140, RBSP_141, RBSP_142, RBSP_143, RBSP_144, RBSP_145, RBSP_146, RBSP_147, RBSP_148, RBSP_149, RBSP_150, RBSP_151, RBSP_152, RBSP_153, RBSP_154, RBSP_155, RBSP_156, RBSP_157, RBSP_158, RBSP_159, RBSP_160, RBSP_1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 | RK73H1ETTP1000F | RESC1005X40N | 402 | SMD | SMD | 100 | 522 | Customer will provide | Resistor - 1%
JD0, JD1, JD2, JD3, JD4, JD5, JD6, JD7, JD8, JD9, JD10, JD11 | SAMTEC_SEAM-50-02.0-L-08-2-A-GP-K-TR | SAMTEC_SEAM-50-02.0-L-08-2-A-GP-K-TR | - | SENS | BGA | - | 12 | Customer will provide | 400 Contacts (50 Contacts x 8 Rows abcdefgh), Pitch 1.27mm, Surface Mount High-Speed/High Density Open-Field Array Board to Board Connector
JP0, JP1, JP2, JP3, JP4, JP5, JP6, JP7, JP8, JP9, JP10, JP11 | SAMTEC_SEAM8-40-S02.0-S-10-2-GP-K_HP | SAMTEC_SEAM8-40-S02.0-S-10-2-GP-K_HP | - | SENS | BGA | - | 12 | Customer will provide | 400 Contacts (40 Contacts x 10 Rows abcdefghjk), Pitch 0.8mm, Surface Mount Ultra-High Density Open-Field Array Board to Board Connector
JPL0, JPL1, JPL2 | SAMTEC_IPBS-115-01-T-D-GP | SAMTEC_IPBS-115-01-T-D-GP | - | THT | TH | - | 3 | Customer will provide | Connector 30 Female
JS_JPL_ONE_1, JS_JPL_ONE_2, JS_JPL_ONE_3, JS_JPL_ONE_4, JS_JPL_ONE_5, JS_JPL_ONE_6, JS_JPL_TWO_1, JS_JPL_TWO_2, JS_JPL_TWO_3, JS_JPL_TWO_4, JS_JPL_TWO_5, JS_JPL_TWO_6, JS_JPL_ZERO_1, JS_JPL_ZERO_2, JS_JPL_ZERO_3, JS_JPL_ZERO_4, JS_JPL_ZERO_5, JS_JPL_ZERO_6, JS_JPU_ONE_1, JS_JPU_ONE_2, JS_JPU_ONE_3, JS_JPU_ONE_4, JS_JPU_ONE_5, JS_JPU_ONE_6, JS_JPU_ONE_7, JS_JPU_ONE_8, JS_JPU_ONE_9, JS_JPU_ONE_10, JS_JPU_ONE_11, JS_JPU_ONE_12, JS_JPU_ONE_13, JS_JPU_ONE_14, JS_JPU_ONE_15, JS_JPU_ONE_16, JS_JPU_ONE_17, JS_JPU_ONE_18, JS_JPU_ONE_19, JS_JPU_ONE_20, JS_JPU_ONE_21, JS_JPU_ONE_22, JS_JPU_ONE_23, JS_JPU_ONE_24, JS_JPU_ONE_25, JS_JPU_ONE_26, JS_JPU_ONE_27, JS_JPU_ONE_28, JS_JPU_ONE_29, JS_JPU_ONE_30, JS_JPU_TWO_1, JS_JPU_TWO_2, JS_JPU_TWO_3, JS_JPU_TWO_4, JS_JPU_TWO_5, JS_JPU_TWO_6, JS_JPU_TWO_7, JS_JPU_TWO_8, JS_JPU_TWO_9, JS_JPU_TWO_10, JS_JPU_TWO_11, JS_JPU_TWO_12, JS_JPU_TWO_13, JS_JPU_TWO_14, JS_JPU_TWO_15, JS_JPU_TWO_16, JS_JPU_TWO_17, JS_JPU_TWO_18, JS_JPU_TWO_19, JS_JPU_TWO_20, JS_JPU_TWO_21, JS_JPU_TWO_22, JS_JPU_TWO_23, JS_JPU_TWO_24, JS_JPU_TWO_25, JS_JPU_TWO_26, JS_JPU_TWO_27, JS_JPU_TWO_28, JS_JPU_TWO_29, JS_JPU_TWO_30, JS_JPU_ZERO_1, JS_JPU_ZERO_2, JS_JPU_ZERO_3, JS_JPU_ZERO_4, JS_JPU_ZERO_5, JS_JPU_ZERO_6, JS_JPU_ZERO_7, JS_JPU_ZERO_8, JS_JPU_ZERO_9, JS_JPU_ZERO_10, JS_JPU_ZERO_11, JS_JPU_ZERO_12, JS_JPU_ZERO_13, JS_JPU_ZERO_14, JS_JPU_ZERO_15, JS_JPU_ZERO_16, JS_JPU_ZERO_17, JS_JPU_ZERO_18, JS_JPU_ZERO_19, JS_JPU_ZERO_20, JS_JPU_ZERO_21, JS_JPU_ZERO_22, JS_JPU_ZERO_23,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 | HARWIN_S9121-45R | HARWIN_S9121-45R | - | SMD | SMD | - | 126 | Customer will provide | Single Pin Female
JT0, JT1, JT2 | SAMTEC_SMS-150-02-L-D | SAMTEC_SMS-150-02-L-D | - | THT | TH | - | 3 | Customer will provide | Connector 100 Female
RT1 | NB-PTCO-330 | TYCO_NB-PTCO-330 | 1206 | SMD | SMD | NB-PTCO-330 | 1 | Customer will provide | 2 Pin Temperature Sensor

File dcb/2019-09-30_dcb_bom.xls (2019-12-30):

Quantity | LibRef | Comment | Description | Designator | Manufacturer | Manufacturer Part Number | Manufacturer1 Part Number | P/N
2 | CC0201_1NF_16V_10%_X5R | 1nF | Non-polarised capacitor | C123, C124 | GENERIC | CC0201_1NF_16V_10%_X5R | 0201YD102KAT2A
54 | CC0805_10UF_10V_10%_X7R | 10uF | Non-polarised capacitor | C1, C13, C14, C72, C127, U1_C21, U1_C22, U1_C37, U1_C38, U1_C53, U1_C54, U1_C129, U2_C21, U2_C22, U2_C37, U2_C38, U2_C53, U2_C54, U2_C129, U3_C21, U3_C22, U3_C37, U3_C38, U3_C53, U3_C54, U3_C129, U4_C21, U4_C22, U4_C37, U4_C38, U4_C53, U4_C54, U4_C129, U5_C21, U5_C22, U5_C37, U5_C38, U5_C53, U5_C54, U5_C129, U6_C21, U6_C22, U6_C37, U6_C38, U6_C53, U6_C54, U6_C129, U_MC_C21, U_MC_C22, U_MC_C37, U_MC_C38, U_MC_C53, U_MC_C54, U_MC_C129 | GENERIC | CC0805_10UF_10V_10%_X7R | GRM21BR71A106KE51L
1 | CERN_GBT-SCA_REV 6.2 | GBT-SCA_REV 6.2 | The Slow Control Adapter ASIC for the GBT System | IC1 | CERN | GBT-SCA_REV 6.2
7 | CERN_GBTX ASIC_V0.1 | GBTX ASIC | GigaBit Transceiver ASIC (GBTX) | U1_IC2, U2_IC2, U3_IC2, U4_IC2, U5_IC2, U6_IC2, U_MC_IC2 | CERN | GBTX ASIC V0.1
4 | DCB Opt. Mod. MATE Holes | DCB Opt. Mod. MATE Holes |  | OMDB23, OMDB45, OMDB61, OMDBMC
1 | FTSH-125-03-L-DV-ES-A | FTSH-125-03-L-DV-ES-A | FTSH-125-03-L-DV-ES-A | J1 | Samtec
167 | GRM033R71C103KE14 | 10 nF | Non-polarised capacitor | C7, C8, C9, C10, C11, C12, C18, C19, C20, C61, C62, C63, C64, C65, C66, C67, C68, C69, C70, C71, C73, C74, C75, C76, C77, C78, C79, C80, C81, C82, C83, C84, C85, C86, C87, C88, C89, C90, C91, C92, C101, C102, C103, C104, C105, C106, C113, C114, C115, C116, C117, C118, C122, C125, C126, U1_C31, U1_C32, U1_C33, U1_C34, U1_C35, U1_C36, U1_C47, U1_C48, U1_C49, U1_C50, U1_C51, U1_C52, U1_C58, U1_C59, U1_C60, U1_C93, U2_C31, U2_C32, U2_C33, U2_C34, U2_C35, U2_C36, U2_C47, U2_C48, U2_C49, U2_C50, U2_C51, U2_C52, U2_C58, U2_C59, U2_C60, U2_C93, U3_C31, U3_C32, U3_C33, U3_C34, U3_C35, U3_C36, U3_C47, U3_C48, U3_C49, U3_C50, U3_C51, U3_C52, U3_C58, U3_C59, U3_C60, U3_C93, U4_C31, U4_C32, U4_C33, U4_C34, U4_C35, U4_C36, U4_C47, U4_C48, U4_C49, U4_C50, U4_C51, U4_C52, U4_C58, U4_C59, U4_C60, U4_C93, U5_C31, U5_C32, U5_C33, U5_C34, U5_C35, U5_C36, U5_C47, U5_C48, U5_C49, U5_C50, U5_C51, U5_C52, U5_C58, U5_C59, U5_C60, U5_C93, U6_C31, U6_C32, U6_C33, U6_C34, U6_C35, U6_C36, U6_C47, U6_C48, U6_C49, U6_C50, U6_C51, U6_C52, U6_C58, U6_C59, U6_C60, U6_C93, U_MC_C31, U_MC_C32, U_MC_C33, U_MC_C34, U_MC_C35, U_MC_C36, U_MC_C47, U_MC_C48, U_MC_C49, U_MC_C50, U_MC_C51, U_MC_C52, U_MC_C58, U_MC_C59, U_MC_C60, U_MC_C93 | Murata | GRM033R71C103KE14
168 | GRM155R71C104KA88 | 100nF | Non-polarised capacitor | C2, C3, C4, C5, C6, C15, C16, C17, C95, C96, C97, C98, C99, C100, C107, C108, C109, C110, C111, C112, C128, U1_C23, U1_C24, U1_C25, U1_C26, U1_C27, U1_C28, U1_C29, U1_C30, U1_C39, U1_C40, U1_C41, U1_C42, U1_C43, U1_C44, U1_C45, U1_C46, U1_C55, U1_C56, U1_C57, U1_C94, U1_C130, U2_C23, U2_C24, U2_C25, U2_C26, U2_C27, U2_C28, U2_C29, U2_C30, U2_C39, U2_C40, U2_C41, U2_C42, U2_C43, U2_C44, U2_C45, U2_C46, U2_C55, U2_C56, U2_C57, U2_C94, U2_C130, U3_C23, U3_C24, U3_C25, U3_C26, U3_C27, U3_C28, U3_C29, U3_C30, U3_C39, U3_C40, U3_C41, U3_C42, U3_C43, U3_C44, U3_C45, U3_C46, U3_C55, U3_C56, U3_C57, U3_C94, U3_C130, U4_C23, U4_C24, U4_C25, U4_C26, U4_C27, U4_C28, U4_C29, U4_C30, U4_C39, U4_C40, U4_C41, U4_C42, U4_C43, U4_C44, U4_C45, U4_C46, U4_C55, U4_C56, U4_C57, U4_C94, U4_C130, U5_C23, U5_C24, U5_C25, U5_C26, U5_C27, U5_C28, U5_C29, U5_C30, U5_C39, U5_C40, U5_C41, U5_C42, U5_C43, U5_C44, U5_C45, U5_C46, U5_C55, U5_C56, U5_C57, U5_C94, U5_C130, U6_C23, U6_C24, U6_C25, U6_C26, U6_C27, U6_C28, U6_C29, U6_C30, U6_C39, U6_C40, U6_C41, U6_C42, U6_C43, U6_C44, U6_C45, U6_C46, U6_C55, U6_C56, U6_C57, U6_C94, U6_C130, U_MC_C23, U_MC_C24, U_MC_C25, U_MC_C26, U_MC_C27, U_MC_C28, U_MC_C29, U_MC_C30, U_MC_C39, U_MC_C40, U_MC_C41, U_MC_C42, U_MC_C43, U_MC_C44, U_MC_C45, U_MC_C46, U_MC_C55, U_MC_C56, U_MC_C57, U_MC_C94, U_MC_C130 | Murata | GRM155R71C104KA88
6 | HIROSE_U.FL-R-SMT-1(10) | U.FL |  | J14, J19, J20, J21, J22, J23 | HIROSE (HRS) | U.FL-R-SMT-1(10)
1 | LED_DIALIGHT_597-2111-407F | Red | LED Red 1C 2A | LD1 | DIALIGHT | 597-2111-407F
15 | LQW31HN23NJ03L_Murata_coil | LQW31HN23NJ03L_Murata_coil |  | L1, U1_L2, U1_L3, U2_L2, U2_L3, U3_L2, U3_L3, U4_L2, U4_L3, U5_L2, U5_L3, U6_L2, U6_L3, U_MC_L2, U_MC_L3 | Murata |  |  | LQW31HN23NJ03L
18 | LRC-LR2010-01-R500-F | 0.5 | Resistor - 1% | R79, R89, R90, R91, U1_R87, U1_R88, U2_R87, U2_R88, U3_R87, U3_R88, U4_R87, U4_R88, U5_R87, U5_R88, U6_R87, U6_R88, U_MC_R87, U_MC_R88 | TT Electronics | LRC-LR-2010LF-01-R50-F
4 | LSHM-130-XX.X-XX-DV-A-S | LSHM-130-XX.X-XX-DV-A-S | 0.50MM TERMINAL/SOCKET COMBO,60PINS. | J6, J7, J16, J17 | SAMTEC
1 | MMBT3904 | MMBT3904 | NPN Transistor | T1 | NXP SEMICONDUCTORS | MMBT3904
10 | NON-PLATED_HOLE3.2 | Non Plated Hole | Single Terminal Socket | NonPlated1, NonPlated2, NonPlated3, NonPlated4, NonPlated5, NonPlated6, NonPlated7, NonPlated8, NonPlated9, NonPlated10
4 | PLATED_HOLE0.8_PAD1.3 | Plated Hole | Single Terminal Socket | B1, B2, B3, B4
13 | R0402_0R_JUMPER | 0 | Resistor | R23, R24, R130, R142, R144, R146, U1_R171, U2_R171, U3_R171, U4_R171, U5_R171, U6_R171, U_MC_R171 | GENERIC | R0402_0R_JUMPER | 232270591001L
19 | R0402_1K3_1%_0.0625W_100PPM | 1k3 | Resistor - 1% | R82, R83, R95, R106, R108, R109, R110, R111, R112, R113, R114, R115, U1_R75, U2_R75, U3_R75, U4_R75, U5_R75, U6_R75, U_MC_R75 | GENERIC | R0402_1K3_1%_0.0625W_100PPM | 232270671302L
39 | R0402_1K_1%_0.0625W_100PPM | 1k | Resistor - 1% | R1, R2, R3, R5, R10, R32, R33, R34, R35, R36, R37, R38, R39, R40, R41, R42, R44, R45, R46, R47, R55, R56, R57, R58, R77, R78, R104, R105, R147, R149, R150, R151, U1_R43, U2_R43, U3_R43, U4_R43, U5_R43, U6_R43, U_MC_R43 | GENERIC | R0402_1K_1%_0.0625W_100PPM | 232270671002L
24 | R0402_2K_1%_0.0625W_100PPM | 2k | Resistor - 1% | R18, R19, R20, R21, R22, R25, R26, R80, R81, R102, R103, R116, R117, R118, R119, R120, R121, R122, R123, R124, R125, R126, R127, R131 | GENERIC | R0402_2K_1%_0.0625W_100PPM | 232270672002L
2 | R0402_10R_1%_0.0625W_200PPM | 10 | Resistor - 1% | R49, R148 | GENERIC | R0402_10R_1%_0.0625W_200PPM | 232270671009L
7 | R0402_30R_1%_0.0625W_100PPM | 30 | Resistor - 1% | R11, R12, R13, R14, R15, R16, R17 | GENERIC | R0402_30R_1%_0.0625W_100PPM | 232270673009L
19 | R0402_51K_1%_0.0625W_100PPM | 51k | Resistor - 1% | R85, R86, R96, R97, R99, R101, R107, R128, R132, R133, R134, R135, R136, R137, R138, R139, R140, R141, R143 | GENERIC | R0402_51K_1%_0.0625W_100PPM | 232270674703L
30 | R0402_51R_1%_0.0625W_100PPM | 51 | Resistor - 1% | R98, R100, U1_R48, U1_R52, U1_R53, U1_R54, U2_R48, U2_R52, U2_R53, U2_R54, U3_R48, U3_R52, U3_R53, U3_R54, U4_R48, U4_R52, U4_R53, U4_R54, U5_R48, U5_R52, U5_R53, U5_R54, U6_R48, U6_R52, U6_R53, U6_R54, U_MC_R48, U_MC_R52, U_MC_R53, U_MC_R54 | GENERIC | R0402_51R_1%_0.0625W_100PPM | 232270675109L
34 | R0402_100R_1%_0.1W_100PPM | 100 | Resistor - 1% | R4, R6, R7, R8, R9, R27, R28, R76, R92, R93, R94, R129, R145, U1_R29, U1_R30, U1_R31, U2_R29, U2_R30, U2_R31, U3_R29, U3_R30, U3_R31, U4_R29, U4_R30, U4_R31, U5_R29, U5_R30, U5_R31, U6_R29, U6_R30, U6_R31, U_MC_R29, U_MC_R30, U_MC_R31 | GENERIC | R0402_100R_1%_0.1W_100PPM_50V | ERJ2RKF1000X
112 | R0402_510R_1%_0.0625W_100PPM | 510 | Resistor - 1% | U1_R59, U1_R60, U1_R61, U1_R62, U1_R63, U1_R64, U1_R65, U1_R66, U1_R67, U1_R68, U1_R69, U1_R70, U1_R71, U1_R72, U1_R73, U1_R74, U2_R59, U2_R60, U2_R61, U2_R62, U2_R63, U2_R64, U2_R65, U2_R66, U2_R67, U2_R68, U2_R69, U2_R70, U2_R71, U2_R72, U2_R73, U2_R74, U3_R59, U3_R60, U3_R61, U3_R62, U3_R63, U3_R64, U3_R65, U3_R66, U3_R67, U3_R68, U3_R69, U3_R70, U3_R71, U3_R72, U3_R73, U3_R74, U4_R59, U4_R60, U4_R61, U4_R62, U4_R63, U4_R64, U4_R65, U4_R66, U4_R67, U4_R68, U4_R69, U4_R70, U4_R71, U4_R72, U4_R73, U4_R74, U5_R59, U5_R60, U5_R61, U5_R62, U5_R63, U5_R64, U5_R65, U5_R66, U5_R67, U5_R68, U5_R69, U5_R70, U5_R71, U5_R72, U5_R73, U5_R74, U6_R59, U6_R60, U6_R61, U6_R62, U6_R63, U6_R64, U6_R65, U6_R66, U6_R67, U6_R68, U6_R69, U6_R70, U6_R71, U6_R72, U6_R73, U6_R74, U_MC_R59, U_MC_R60, U_MC_R61, U_MC_R62, U_MC_R63, U_MC_R64, U_MC_R65, U_MC_R66, U_MC_R67, U_MC_R68, U_MC_R69, U_MC_R70, U_MC_R71, U_MC_R72, U_MC_R73, U_MC_R74 | GENERIC | R0402_510R_1%_0.0625W_100PPM | 232270675101L
14 | R0402_750R_1%_0.0625W_100PPM | 750 | Resistor - 1% | U1_R50, U1_R51, U2_R50, U2_R51, U3_R50, U3_R51, U4_R50, U4_R51, U5_R50, U5_R51, U6_R50, U6_R51, U_MC_R50, U_MC_R51 | GENERIC | R0402_750R_1%_0.0625W_100PPM | 232270677501L
6 | R0805_0R_JUMPER | 0-DNI | Resistor | R152, R156, R159, R160, R161, R166 | GENERIC | R0805_0R_JUMPER | NRC10Z0
14 | R0805_0R_JUMPER | 0 | Resistor | R84, R153, R154, R155, R157, R158, R162, R163, R164, R165, R167, R168, R169, R170 | GENERIC | R0805_0R_JUMPER | NRC10Z0
7 | SAMTEC_TMM-103-01-L-D-SM-P-TR | Header 6 | Connector 6 Male | J2, J4, J10, J12, J13, J15, J18 | SAMTEC | TMM-103-01-L-D-SM-P-TR
3 | SAMTEC_TMM-112-01-L-D-SM-A | Header 24 | Connector 24 Male | J5, J8, J9 | SAMTEC | TMM-112-01-L-D-SM-A
1 | SEAF-50-01-X-08-X-RA-GP | SEAF-50-01-X-08-X-RA-GP | SEAF-RA ASSEMBLY. | J3 | SAMTEC
24 | SMD_PAD_1.27X1.27MM | Test Point | Test Point | TP3, TP4, TP6, U1_TP1, U1_TP2, U1_TP5, U2_TP1, U2_TP2, U2_TP5, U3_TP1, U3_TP2, U3_TP5, U4_TP1, U4_TP2, U4_TP5, U5_TP1, U5_TP2, U5_TP5, U6_TP1, U6_TP2, U6_TP5, U_MC_TP1, U_MC_TP2, U_MC_TP5
3 | T520B227M004ATE045 | 220uF | Polarised capacitor | C119, C120, C121 | KEMET | T520B227M004ATE045
1 | THERM_1206_SMD_Platinum_1K_TE_CONN_NB-PTCO-330_ | 1K | Thermistor NTC (Negative Temperature Coefficient) | RT1 | TE Connectivity Measurement Specialities | NB-PTCO-330

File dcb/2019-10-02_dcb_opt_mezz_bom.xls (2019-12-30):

Comment | DECSRIPTION | Description | Designator | Footprint | LibRef | Manufacturer Part Number | Manufacturer | Package | Part Description | Quantity
47uF |  | Non-polarised capacitor | C1, C2 | CAPC3225X270N | CC1210_47UF_10V_10%_X7R | GCJ32ER70J476KE01L | Murata |  | Non-polarised ceramic capacitor, X7T, 47.0uF, 6.3V, +/-10% tol | 2
100nF |  | Non-polarised capacitor | C3, C4, C7, C8 | CAPC1005X55N | GRM155R71C104KA88 | GCM155R71C104KA55D | Murata |  | Non-polarised ceramic capacitor, X7R, 0.1uF, 16V, +/-10% tol (automotive grade) | 4
10 nF |  | Non-polarised capacitor | C5, C6 | CAPC0603X33N | GRM033R71C103KE14 | GRM033R71C103KE14 | Murata |  | Non-polarised ceramic capacitor, X7R, 0.01uF, 16V, +/-10% tol | 2
LSHM-130-XX.X-XX-DV-A-S |  | 0.50MM TERMINAL/SOCKET COMBO,60PINS. | J1 | LSHM-130-XX.X-XX-DV-A-S | LSHM-130-XX.X-XX-DV-A-S | LSHM-130-06.0-L-DV-A-S-K | Samtec |  | High-speed hermaphroditic strip, 2x30, 10um gold, shield, pick-N-Place pad | 1
SFP+ |  | 20 Position SFP+ Connector (Small Form-factor Pluggable) VTTX (Versatile Twin Transmitter) Pinout | J2 | TYCO_1888247-1 | TYCO_1888247-1_a | 1888247-1 | Tyco |  | Connector for SFP optical module, gold contact finish, 20 contacts | 1
HIROSE_FH41-40S-0.5SH(05) |  | 40 Contacts, 0.5mm Pitch, 2.5mm, Horizontal Mounting, High Speed Transmission Connector for Shielded FFC, FH41 Serie | J3 | HIROSE_FH41-40S-0.5SH(05) | HIROSE_FH41-40S-0.5SH(05) | FH41-40S-0.5SH(05) | Hirose |  | Connector, 40 position, 0.5mm pitch, right angle, gold contact, mates with FFC | 1
U.FL |  |  | J4, J5 | HIROSE_U.FL-R-SMT-1(10) | HIROSE_U.FL-R-SMT-1(10) | U.FL-R-SMT-1(10) | Hirose |  | U.FL, Ultra Miniature Coaxial Connector Receptacle, Male Pin 50 Ohm Surface Mount Solder | 2
LQW31HN23NJ03L_Murata_coil | 0.590A, 46mOhms |  | L1, L2 | LQW31HN23NJ03L_Murata_coil | LQW31HN23NJ03L_Murata_coil | LQW31HN23NJ03L | Murata | 1206 | 23nH Unshielded Wirewound Inductor, 590mA @ 46 mOhm Max, 1206 (3216 Metric) | 2
0R5 |  | Resistor - 1% | R1, R3 | RESC2012X60N | R0805_0R5_1%_0.125W_200PPM | RL1220S-R50-F | Susumu |  | Resistor 0.500 Ohms, +/-1% tol, 0.333W, | 2
Undefined |  | Resistor | R2 | RESC1005X40N | R0402_NO-VALUE | DNI |  |  | Reserved Footprint For a 0402 (1005) Chip Resistor | 1
100 |  | Resistor - 1% | R4, R5 | RESC1005X40N | R0402_100R_1%_0.0625W_100PPM | CRCW0402100RJNED | Vishay Dale |  | Resistor 100 Ohms, +/-5% tol, 0.063W, | 2
0 |  | Resistor | R6, R7, R8 | RESC2012X60N | R0805_0R_JUMPER | CRCW08050000Z0EAHP | Vishay Dale |  | Resistor 0.0 Ohms Shunt Jumper | 3
4.7K |  | Thermistor NTC (Negative Temperature Coefficient) | RT1 | THERMC2013X95N | THERM_NTC_4.7K_TDK B57471V2472J062 | B57471V2472J062 | TDK |  | 4.7K thermistor, NTC, 5% tol | 1

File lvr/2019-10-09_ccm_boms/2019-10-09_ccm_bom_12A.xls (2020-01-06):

Comment | Description | Designator | Footprint | LibRef | Quantity
Plated Hole | Single Terminal Socket | B6, B7 | C55H30 | PLATED_HOLE0.3_PAD0.55 | 2
1nF | Non-polarised capacitor | C1, C117 | CAPC1005X55N | CC0402_1NF_50V_10%_X7R | 2
100nF | Non-polarised capacitor | C30, C36, C43 | CAPC1005X55N | CC0402_100NF_16V_10%_X7R | 3
4.7uF | Non-polarised capacitor | C45, C124, C129 | CAPC2012X135N | CC0805_4.7UF_16V_10%_X7R | 3
10nF | Non-polarised capacitor | C51 | CAPC1005X55N | CC0402_10NF_25V_10%_X7R | 1
22nF | Non-polarised capacitor | C_M1 | CAPC2013X100N | CC0805_22NF_25V_1%_C0G | 1
68nF | Non-polarised capacitor | C_MS1 | CAPC2012X135N | CC0805_68NF_25V_10%_X7R | 1
TFM-115-X2-XXX-D-A | 0.050" TERMINAL STRIP, SURFACE MOUNT ASSEMBLY. | CC8 | TFM-115-X2-XXX-D-A | TFM-115-X2-XXX-D-A | 1
Use only in PCB | Fiducial Target | FTG1, FTG2, FTG4, FTG5 | FIDUCIAL_TOP_C100-200 | FIDUCIAL_TARGET_C100-200 | 4
=Family | Test Point | Gnd1, Gnd2, Vos1, Vsense | TYCO_RCT-0C | TYCO_RCT-0C | 4
Non Plated Hole | Single Terminal Socket | Hole3mm_A, Hole3mm_B | MTG300 | NON-PLATED_HOLE3.0 | 2
MAX4238AUT+T | Ultra-Low Offset/Drift, Low-Noise, Precision Amplifiers | IC8, IC9, IC10 | SOT95P280X145-6N | MAX4238AUT+T | 3
100k | Trimming Potentiometer | POT-1 | TRIM_BOURNS_3314G-1 | TRIM_1T_10K_BOURNS_3314G-1-103E | 1
470 | Resistor - 1% | R4 | RESC1005X40N | R0402_470R_1%_0.0625W_100PPM | 1
2k05 | Resistor - 0.1% | R5 | RESC2012X60N | R0805_2K05_0.1%_0.1W_10PPM | 1
22k6 | Resistor - 0.1% | R9, R_VSET1 | RESC2012X60N | R0805_22K6_0.1%_0.1W_10PPM | 2
6k2 | Resistor - 1% | R71, R100, R118 | RESC1005X40N | R0402_6K2_1%_0.0625W_100PPM | 3
1k1 | Resistor - 1% | R75, R77 | RESC1005X40N | R0402_1K1_1%_0.0625W_100PPM | 2
5R1 | Resistor - 1% | R76 | RESC2012X60N | R0805_5R1_1%_0.5W_100PPM_VISHAY_CRCW-HP | 1
2k | Resistor - 1% | R95, R96 | RESC1005X40N | R0402_2K_1%_0.0625W_100PPM | 2
0 | Resistor | R_M1, R_M2, R_M3, R_M4, R_M5, R_M6 | RESC2012X60N | R0805_0R_JUMPER | 6
100 | Resistor - 1% | R_M7, R_MS1 | RESC2012X60N | R0805_100R_1%_0.125W_100PPM | 2
2K | DIL8 Resistor Network 4 Isolated Resistor 0.1% | RN4, RN5 | RN_VISHAY_ACAS0612 | RN_2K_VISHAY_ACASA2001S2001P100 | 2

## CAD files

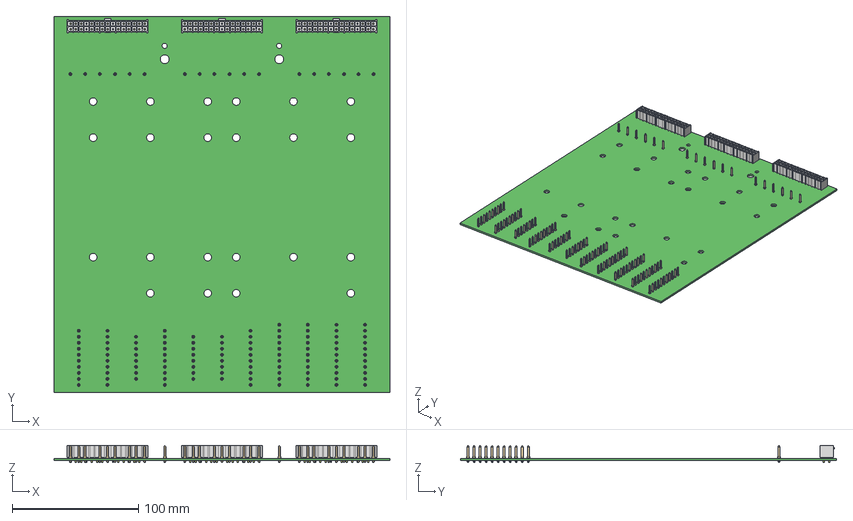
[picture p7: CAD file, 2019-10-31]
backplane/mechanics/2019-10-28_true_P2B2.step
266.0 x 298.0 x 13.8 mm
keystone-PN1362-2 x 126
_IPBT-115-H1-T-D-K_terminal x 3
_IPBT-115-H1-D_pin x 3

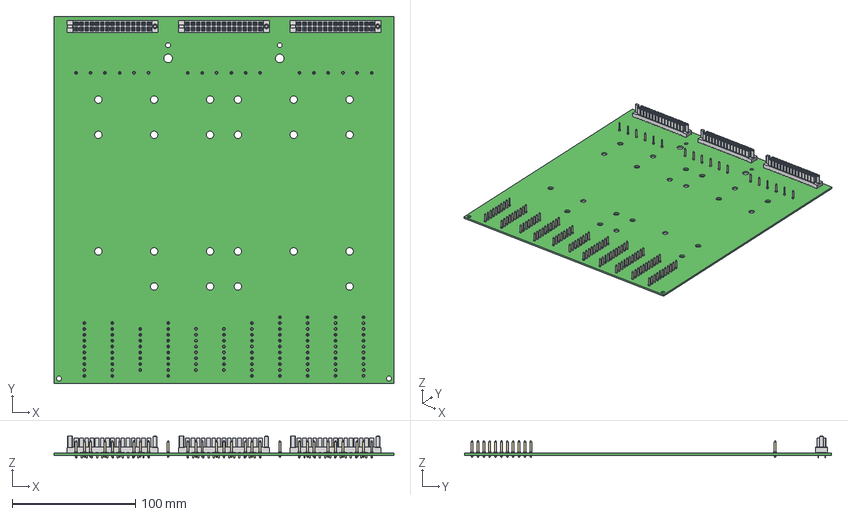
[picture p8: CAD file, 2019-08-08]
backplane/mechanics/2019-07-15_P2B2.step
276.0 x 298.0 x 17.8 mm
keystone-PN1362-2 x 126
_IPBS-115-XX-D-GP_socket x 3
_C-168-01-15-D x 3

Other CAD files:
backplane/mechanics/2019-10-10_mirror_P2B2.step

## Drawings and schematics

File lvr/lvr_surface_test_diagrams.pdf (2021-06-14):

1

2

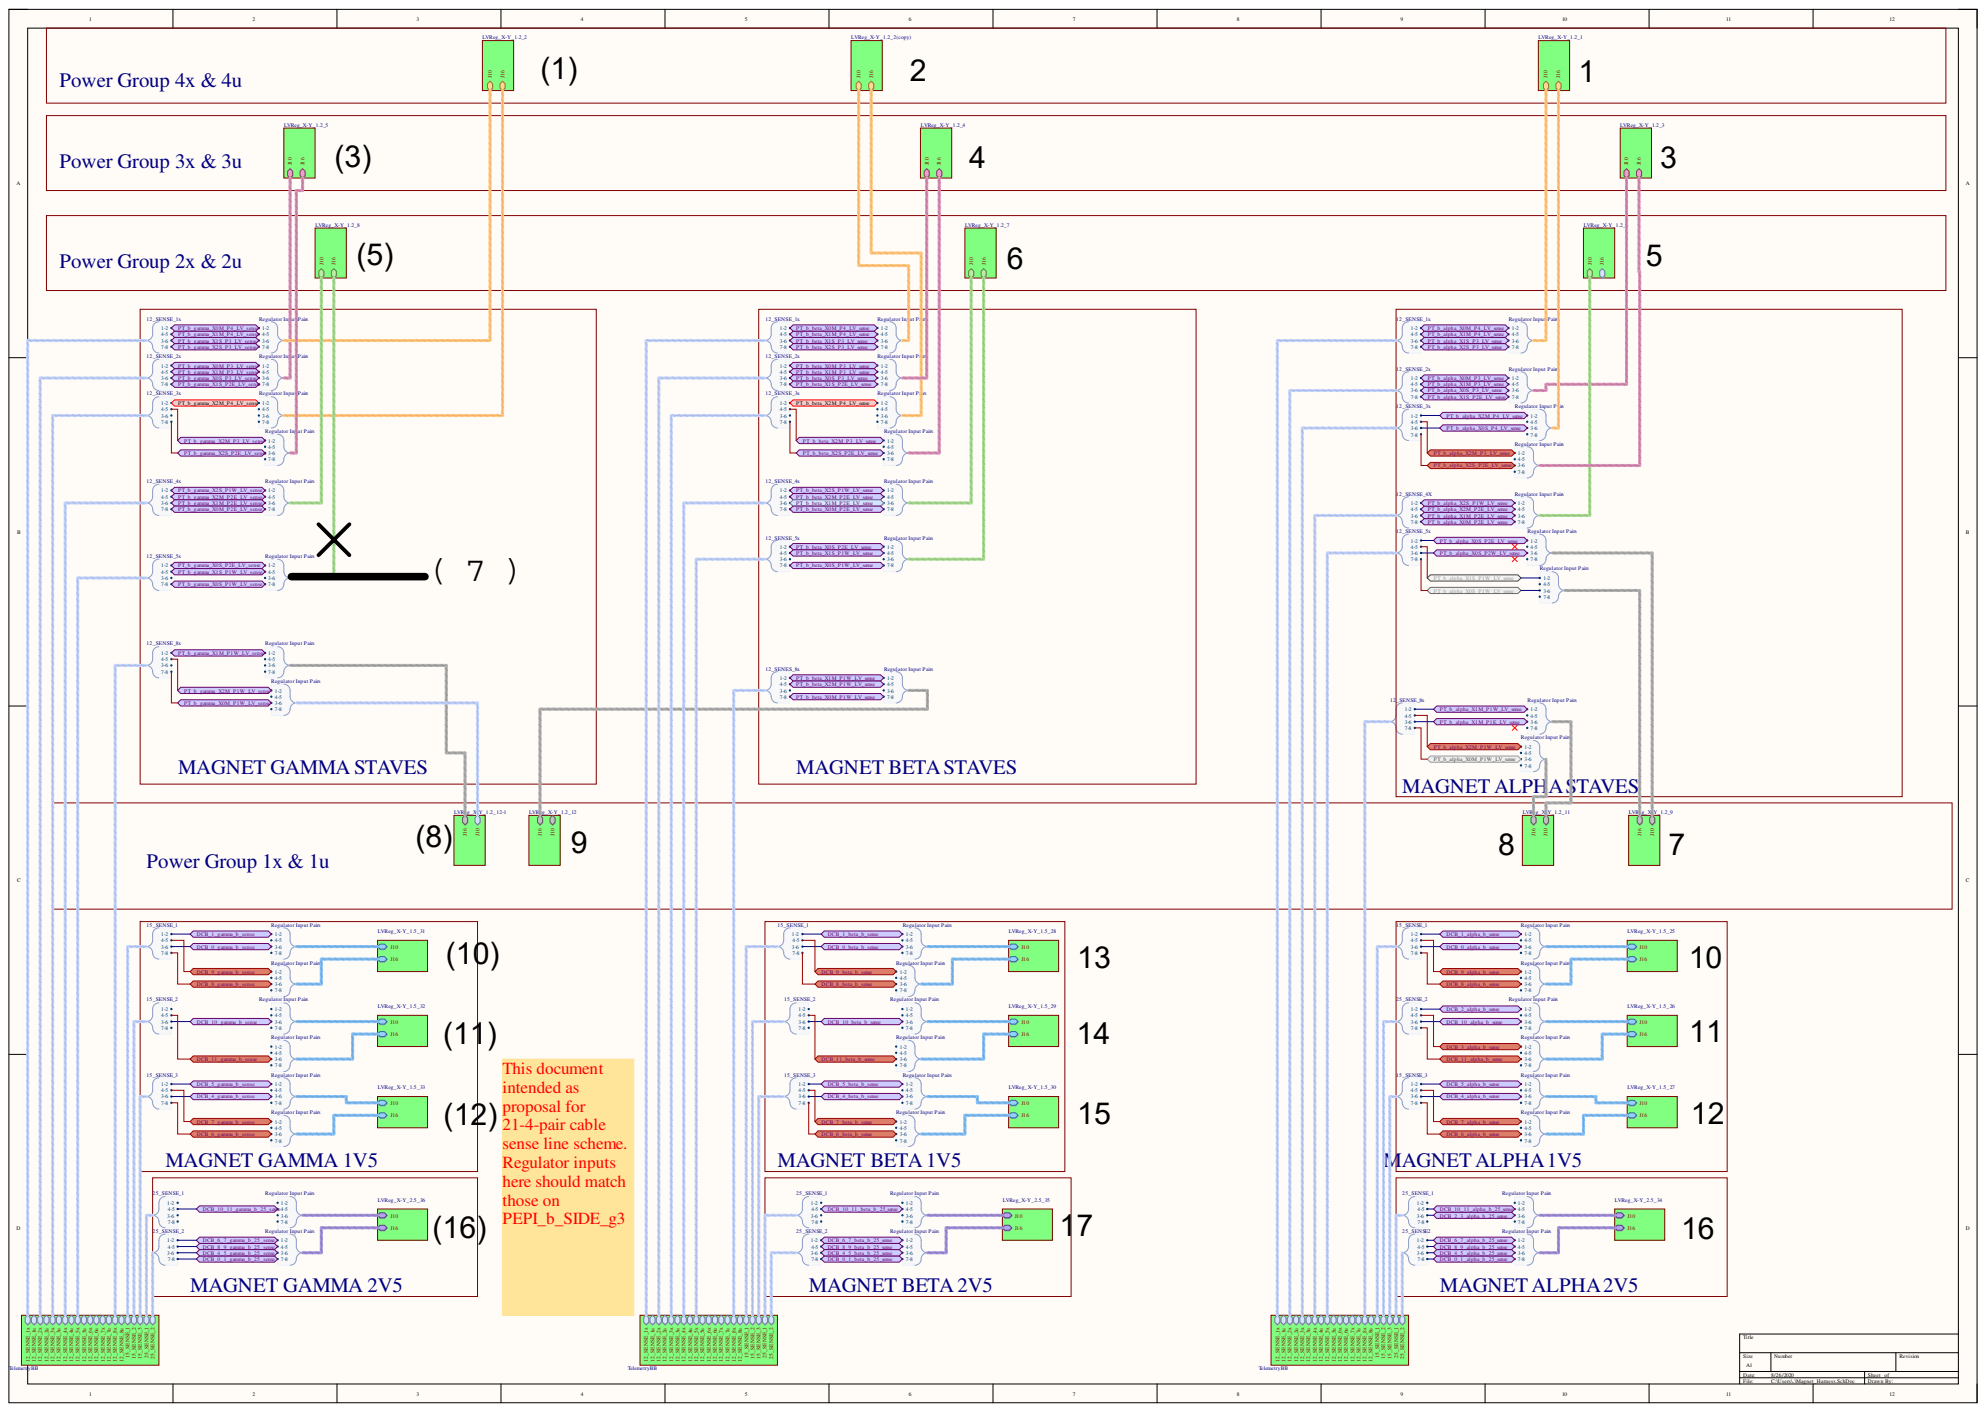
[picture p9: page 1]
Title; Size; Number; Revision; Date:; Sheet of; File:; C:\Users\..\Magnet_Harness.SchDoc; Drawn By:; 12_SENSE_1x; 12_SENSE_2x; 12_SENSE_3x; 12_SENSE_4X; 12_SENSE_5x; 12_SENSE_8x; Regulator Input Pairs; PT_b_alpha_X1M_P4_LV_sense PT_b_alpha_X1S_P3_LV_sense; PT_b_alpha_X0M_P4_LV_sense; PT_b_alpha_X2S_P3_LV_sense; PT_b_alpha_X1M_P3_LV_sense PT_b_alpha_X0S_P3_LV_sense; PT_b_alpha_X0M_P3_LV_sense; PT_b_alpha_X1S_P2E_LV_sense; PT_b_alpha_X2M_P3_LV_sense; PT_b_alpha_X2S_P2E_LV_sense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

Regulator Input Pairs

PT_b_alpha_X2M_P1W_LV_sense
MAGNET ALPHA STAVES

MAGNET GAMMA STAVES

MAGNET BETA STAVES

proposal for
21-4-pair cable
sense line scheme.
Regulator inputs
here should match
those on

1.5 V Rail | 2.5V Rail

# PEPI Magnet ("b" planes) power

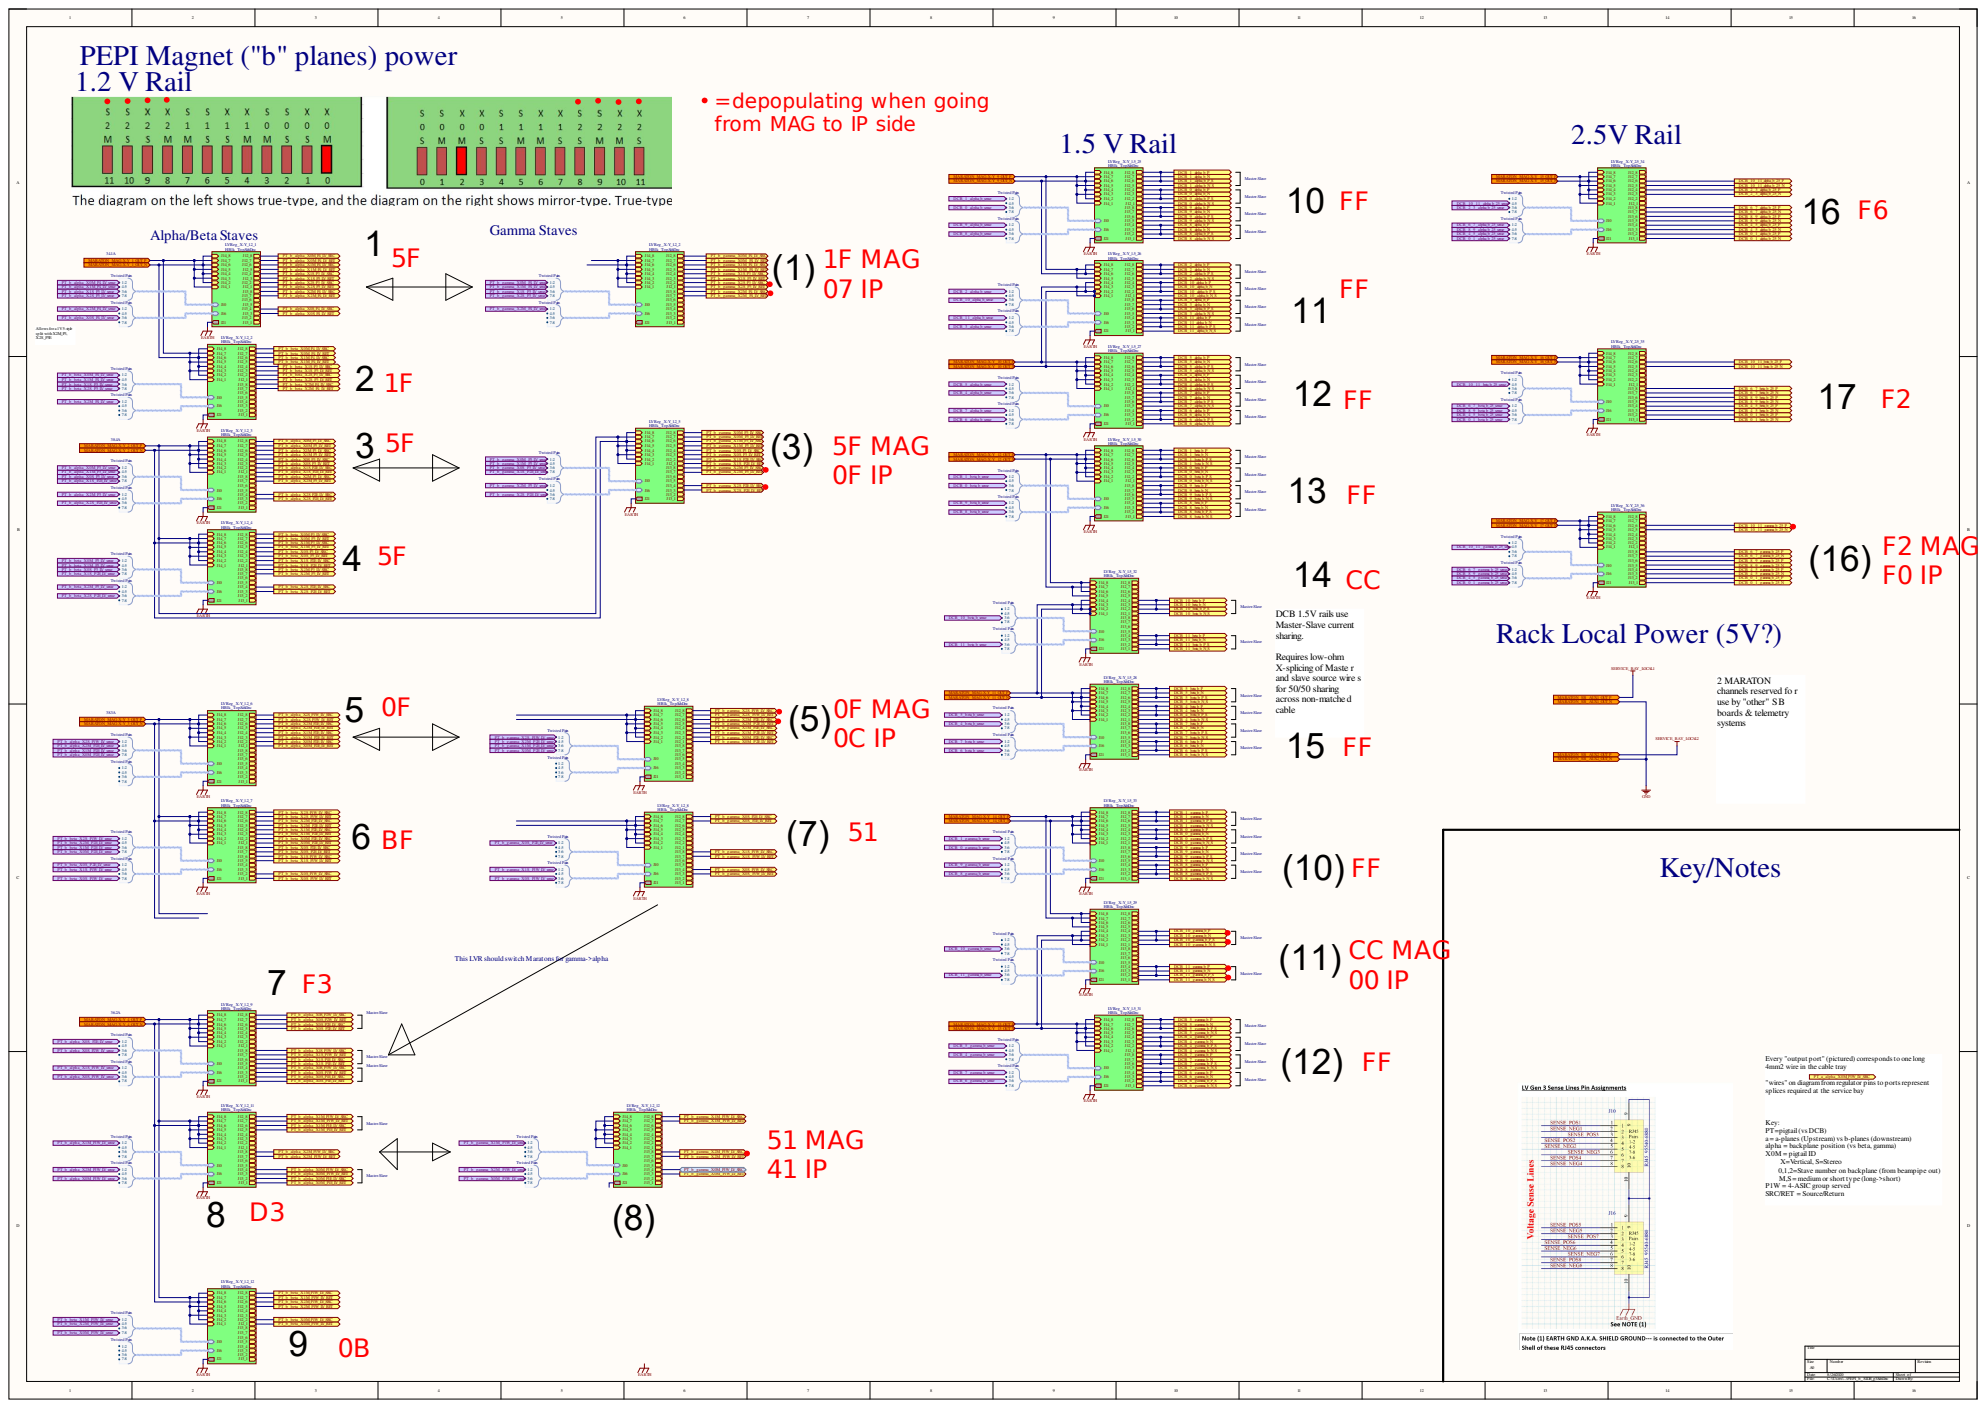
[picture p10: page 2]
Title; Size; Number; Revision; Date:; Sheet of; File:; C:\Users\..\PEPI_b_SIDE_g3.SchDoc; Drawn By:; LVReg_X-Y_1.2_1 HBlk_Top.SchDoc; MARATON_MAG-X-Y_1_OUT_P MARATON_MAG-X-Y_1_OUT_N; MARATON_MAG-X-Y_2_OUT_P MARATON_MAG-X-Y_2_OUT_N; MARATON_MAG-X-Y_3_OUT_P MARATON_MAG-X-Y_3_OUT_N; MARATON_MAG-X-Y_4_OUT_P MARATON_MAG-X-Y_4_OUT_N; MARATON_MAG-X-Y_9_OUT_P MARATON_MAG-X-Y_9_OUT_N; MARATON_MAG-X-Y_10_OUT_P MARATON_MAG-X-Y_10_OUT_N; MARATON_MAG-X-Y_15_OUT_P MARATON_MAG-X-Y_15_OUT_N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

=depopulating when going
from MAG to IP side

Alpha/Beta Staves

Allows for a 1V5-style
split with X2M_P3,

DCB 1.5V rails use
Master-Slave current
sharing.

Requires low-ohm
X-splicing of Maste r
and slave source wire s
for 50/50 sharing
across non-matched
cable

2 MARATON
channels reserved fo r
use by "other" SB
boards & telemetry
systems

This LVR should switch Maratons for gamma->alpha

Every "output port" (pictured) corresponds to one long
4mm2 wire in the cable tray

"wires" on diagram from regulator pins to ports represent
splices required at the service bay

Key:
PT=pigtail (vs DCB)
a = a-planes (Upstream) vs b-planes (downstream)
alpha = backplane position (vs beta, gamma)
X0M = pigtail ID
X=Vertical, S=Stereo
0,1,2=Stave number on backplane (from beampipe out)
M,S = medium or short type (long->short)
P1W = 4-ASIC group served
SRC/RET = Source/Return

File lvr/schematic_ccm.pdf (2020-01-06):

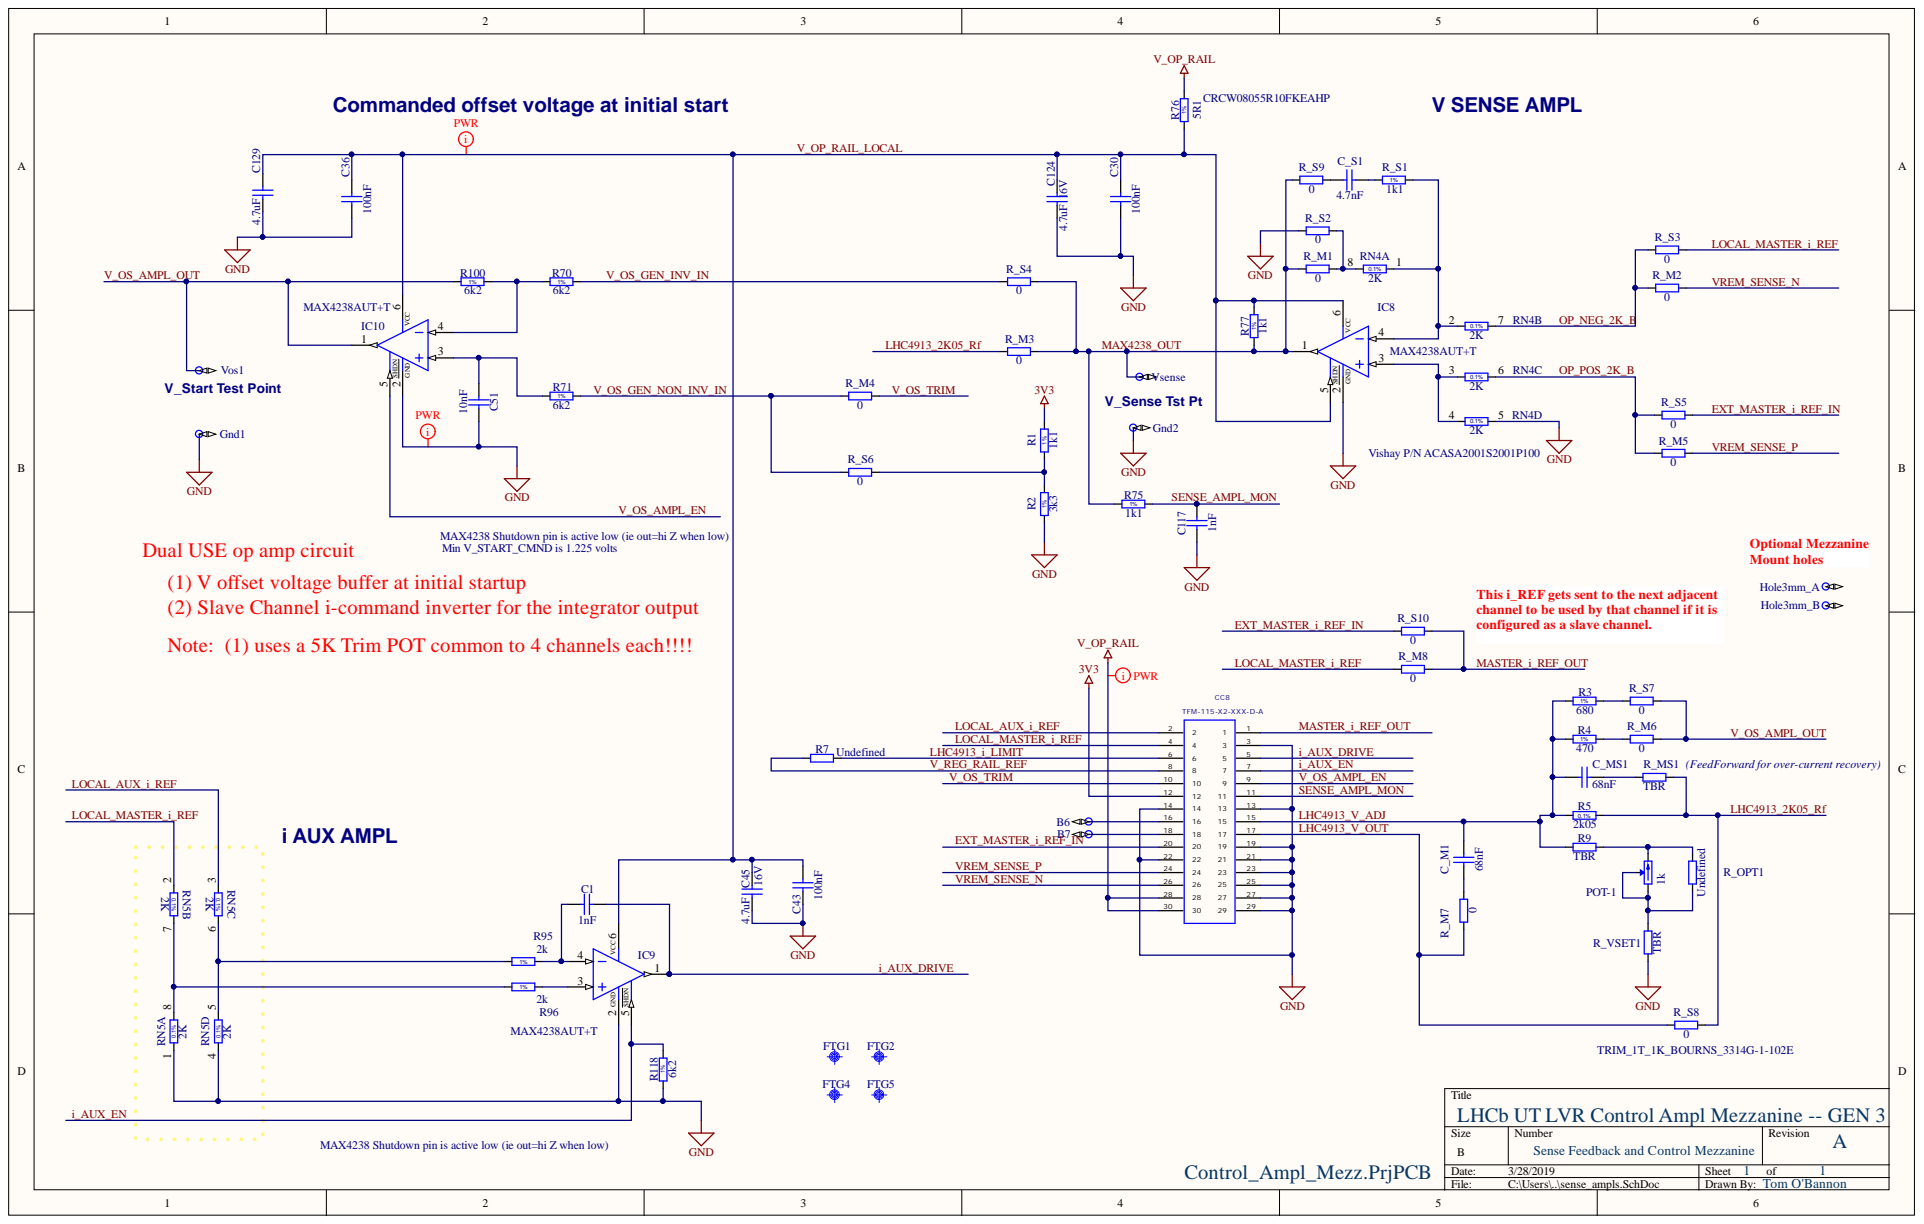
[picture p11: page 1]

V_OP_RAIL

Commanded offset voltage at initial start

MAX4238 Shutdown pin is active low (ie out=hi Z when low)
Min V_START_CMND is 1.225 volts

Dual USE op amp circuit
(1) V offset voltage buffer at initial startup
(2) Slave Channel i-command inverter for the integrator output

This i_REF gets sent to the next adjacent
channel to be used by that channel if it is
configured as a slave channel.

Note: (1) uses a 5K Trim POT common to 4 channels each!!!!

V_REG_RAIL_REF | i_AUX_EN

V_OS_AMPL_EN
SENSE_AMPL_MON

(FeedForward for over-current recovery)

Title
LHCb UT LVR Control Ampl Mezzanine -- GEN 3

A Sense Feedback and Control Mezzanine

Date: 3/28/2019 | 1 1 Tom O'Bannon Sheet of
File: C:\Users\..\sense_ampls.SchDoc | Drawn By:

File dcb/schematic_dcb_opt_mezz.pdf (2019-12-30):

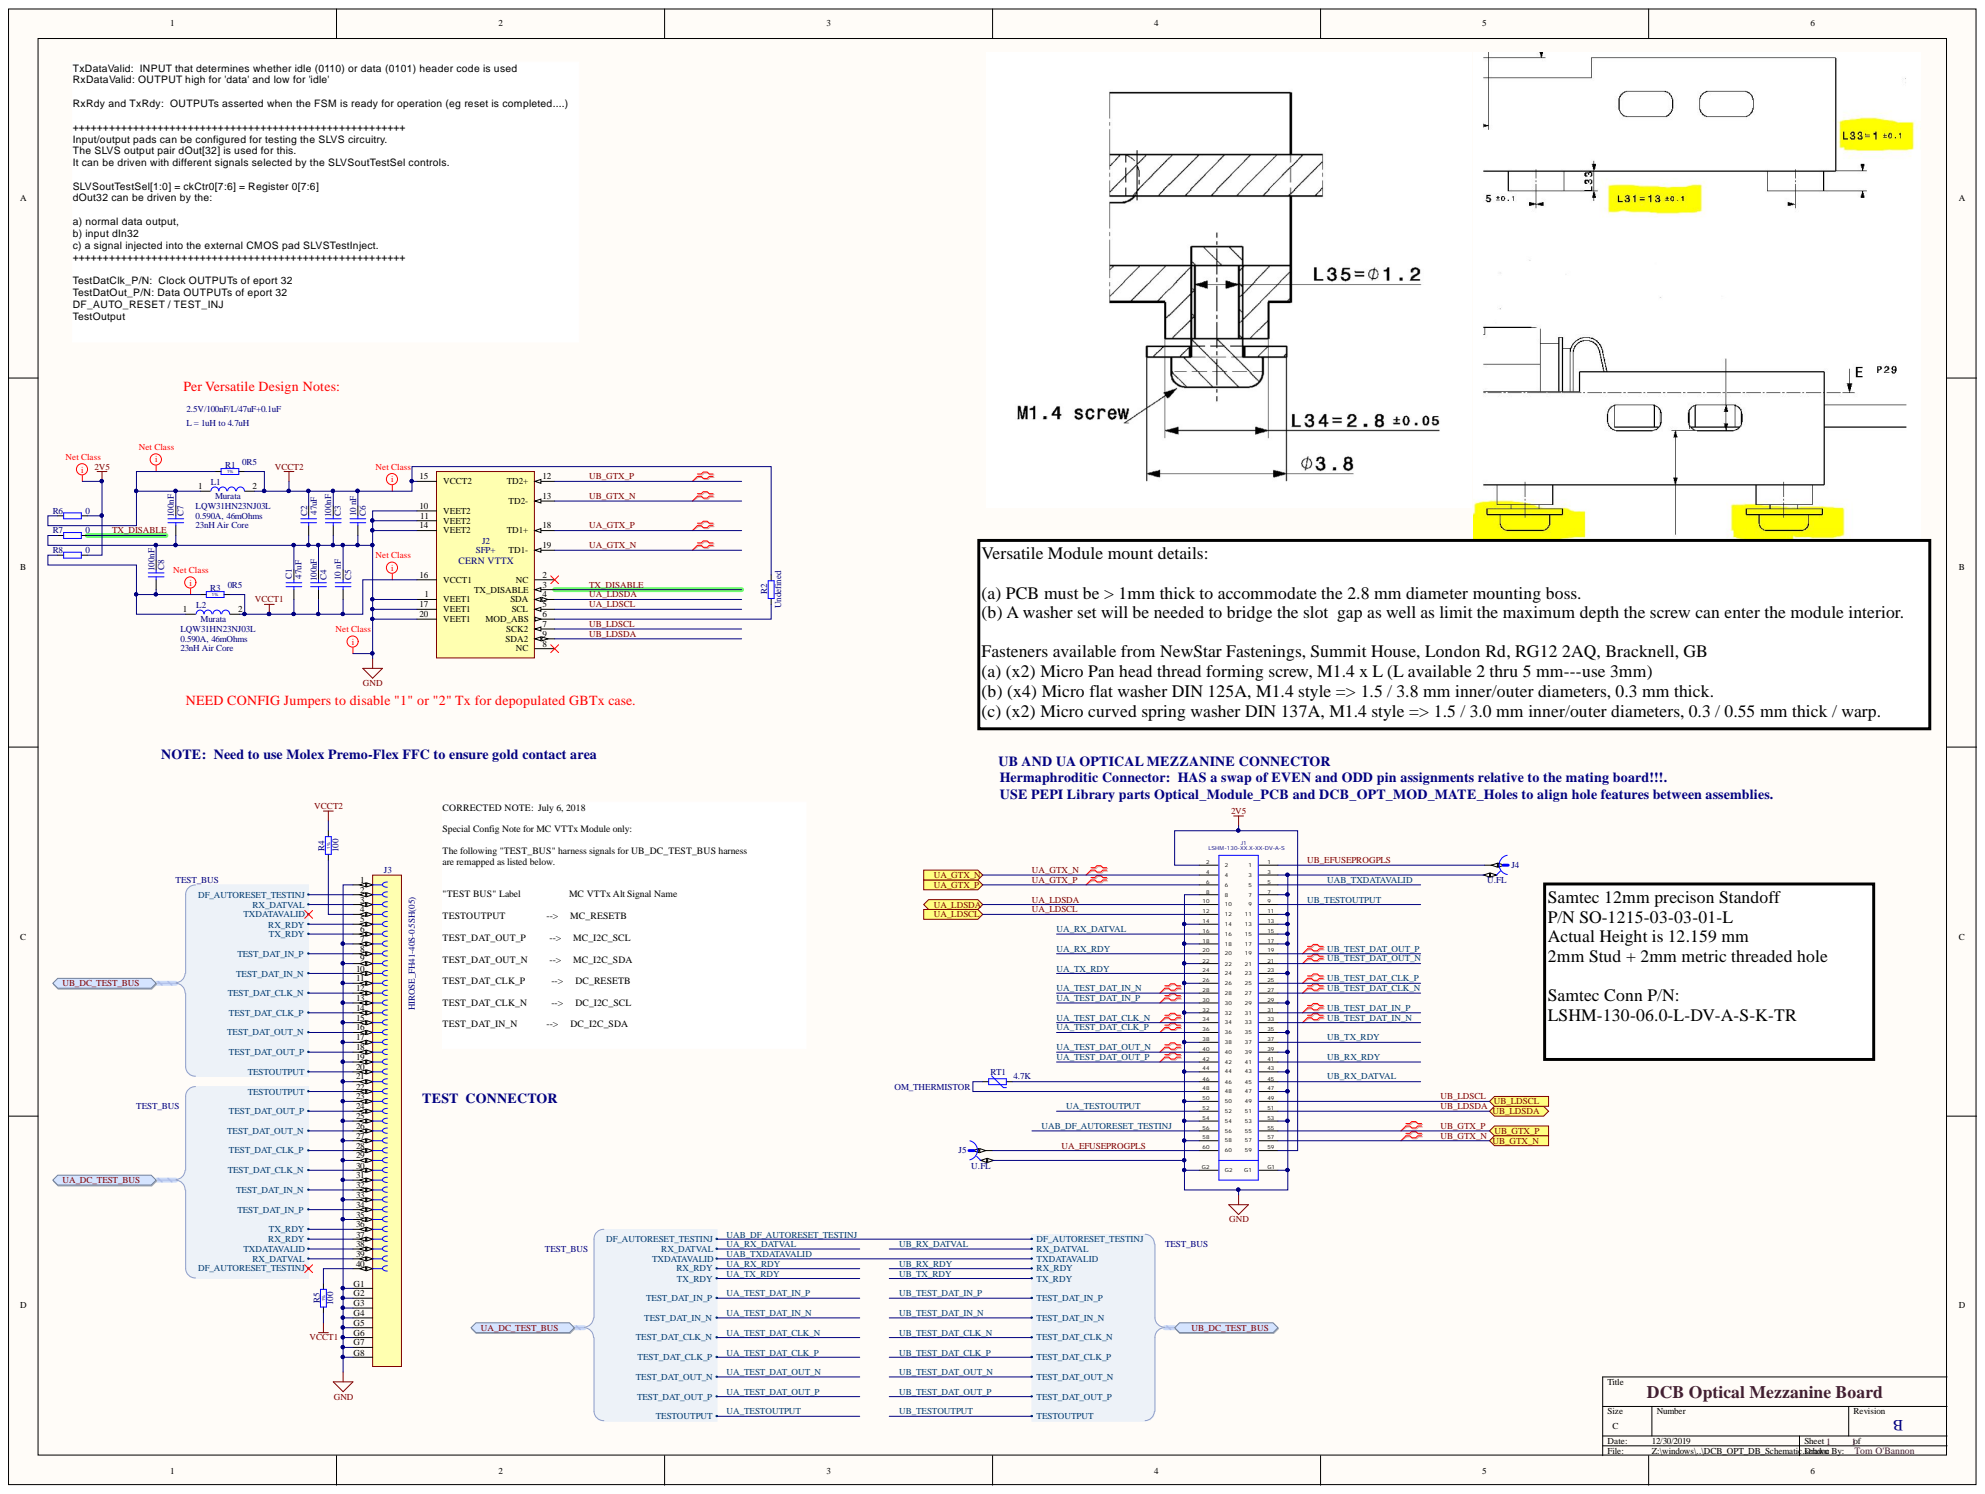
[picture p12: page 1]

TxDataValid: INPUT that determines whether idle (0110) or data (0101) header code is used
RxDataValid: OUTPUT high for 'data' and low for 'idle'

RxRdy and TxRdy: OUTPUTs asserted when the FSM is ready for operation (eg reset is completed....)

Input/output pads can be configured for testing the SLVS circuitry.
The SLVS output pair dOut[32] is used for this.
It can be driven with different signals selected by the SLVSoutTestSel controls.

SLVSoutTestSel[1:0] = ckCtr0[7:6] = Register 0[7:6]
dOut32 can be driven by the:

a) normal data output,
b) input dIn32
c) a signal injected into the external CMOS pad SLVSTestInject.

TestDatClk_P/N: Clock OUTPUTs of eport 32
TestDatOut_P/N: Data OUTPUTs of eport 32
DF_AUTO_RESET / TEST_INJ
TestOutput

Per Versatile Design Notes:

VEET2 10

VEET2 14

Versatile Module mount details:

Net Class i

(a) PCB must be > 1mm thick to accommodate the 2.8 mm diameter mounting boss.
(b) A washer set will be needed to bridge the slot gap as well as limit the maximum depth the screw can enter the module interior.

Fasteners available from NewStar Fastenings, Summit House, London Rd, RG12 2AQ, Bracknell, GB
(a) (x2) Micro Pan head thread forming screw, M1.4 x L (L available 2 thru 5 mm---use 3mm)
(b) (x4) Micro flat washer DIN 125A, M1.4 style => 1.5 / 3.8 mm inner/outer diameters, 0.3 mm thick.
(c) (x2) Micro curved spring washer DIN 137A, M1.4 style => 1.5 / 3.0 mm inner/outer diameters, 0.3 / 0.55 mm thick / warp.

NEED CONFIG Jumpers to disable "1" or "2" Tx for depopulated GBTx case.

NOTE: Need to use Molex Premo-Flex FFC to ensure gold contact area

UB AND UA OPTICAL MEZZANINE CONNECTOR
Hermaphroditic Connector: HAS a swap of EVEN and ODD pin assignments relative to the mating board!!!.
USE PEPI Library parts Optical_Module_PCB and DCB_OPT_MOD_MATE_Holes to align hole features between assemblies.

Special Config Note for MC VTTx Module only:

The following "TEST_BUS" harness signals for UB_DC_TEST_BUS harness
are remapped as listed below.

J1 LSHM-130-XX.X-XX-DV-A-S

Samtec 12mm precison Standoff
Actual Height is 12.159 mm
2mm Stud + 2mm metric threaded hole

Title
DCB Optical Mezzanine Board

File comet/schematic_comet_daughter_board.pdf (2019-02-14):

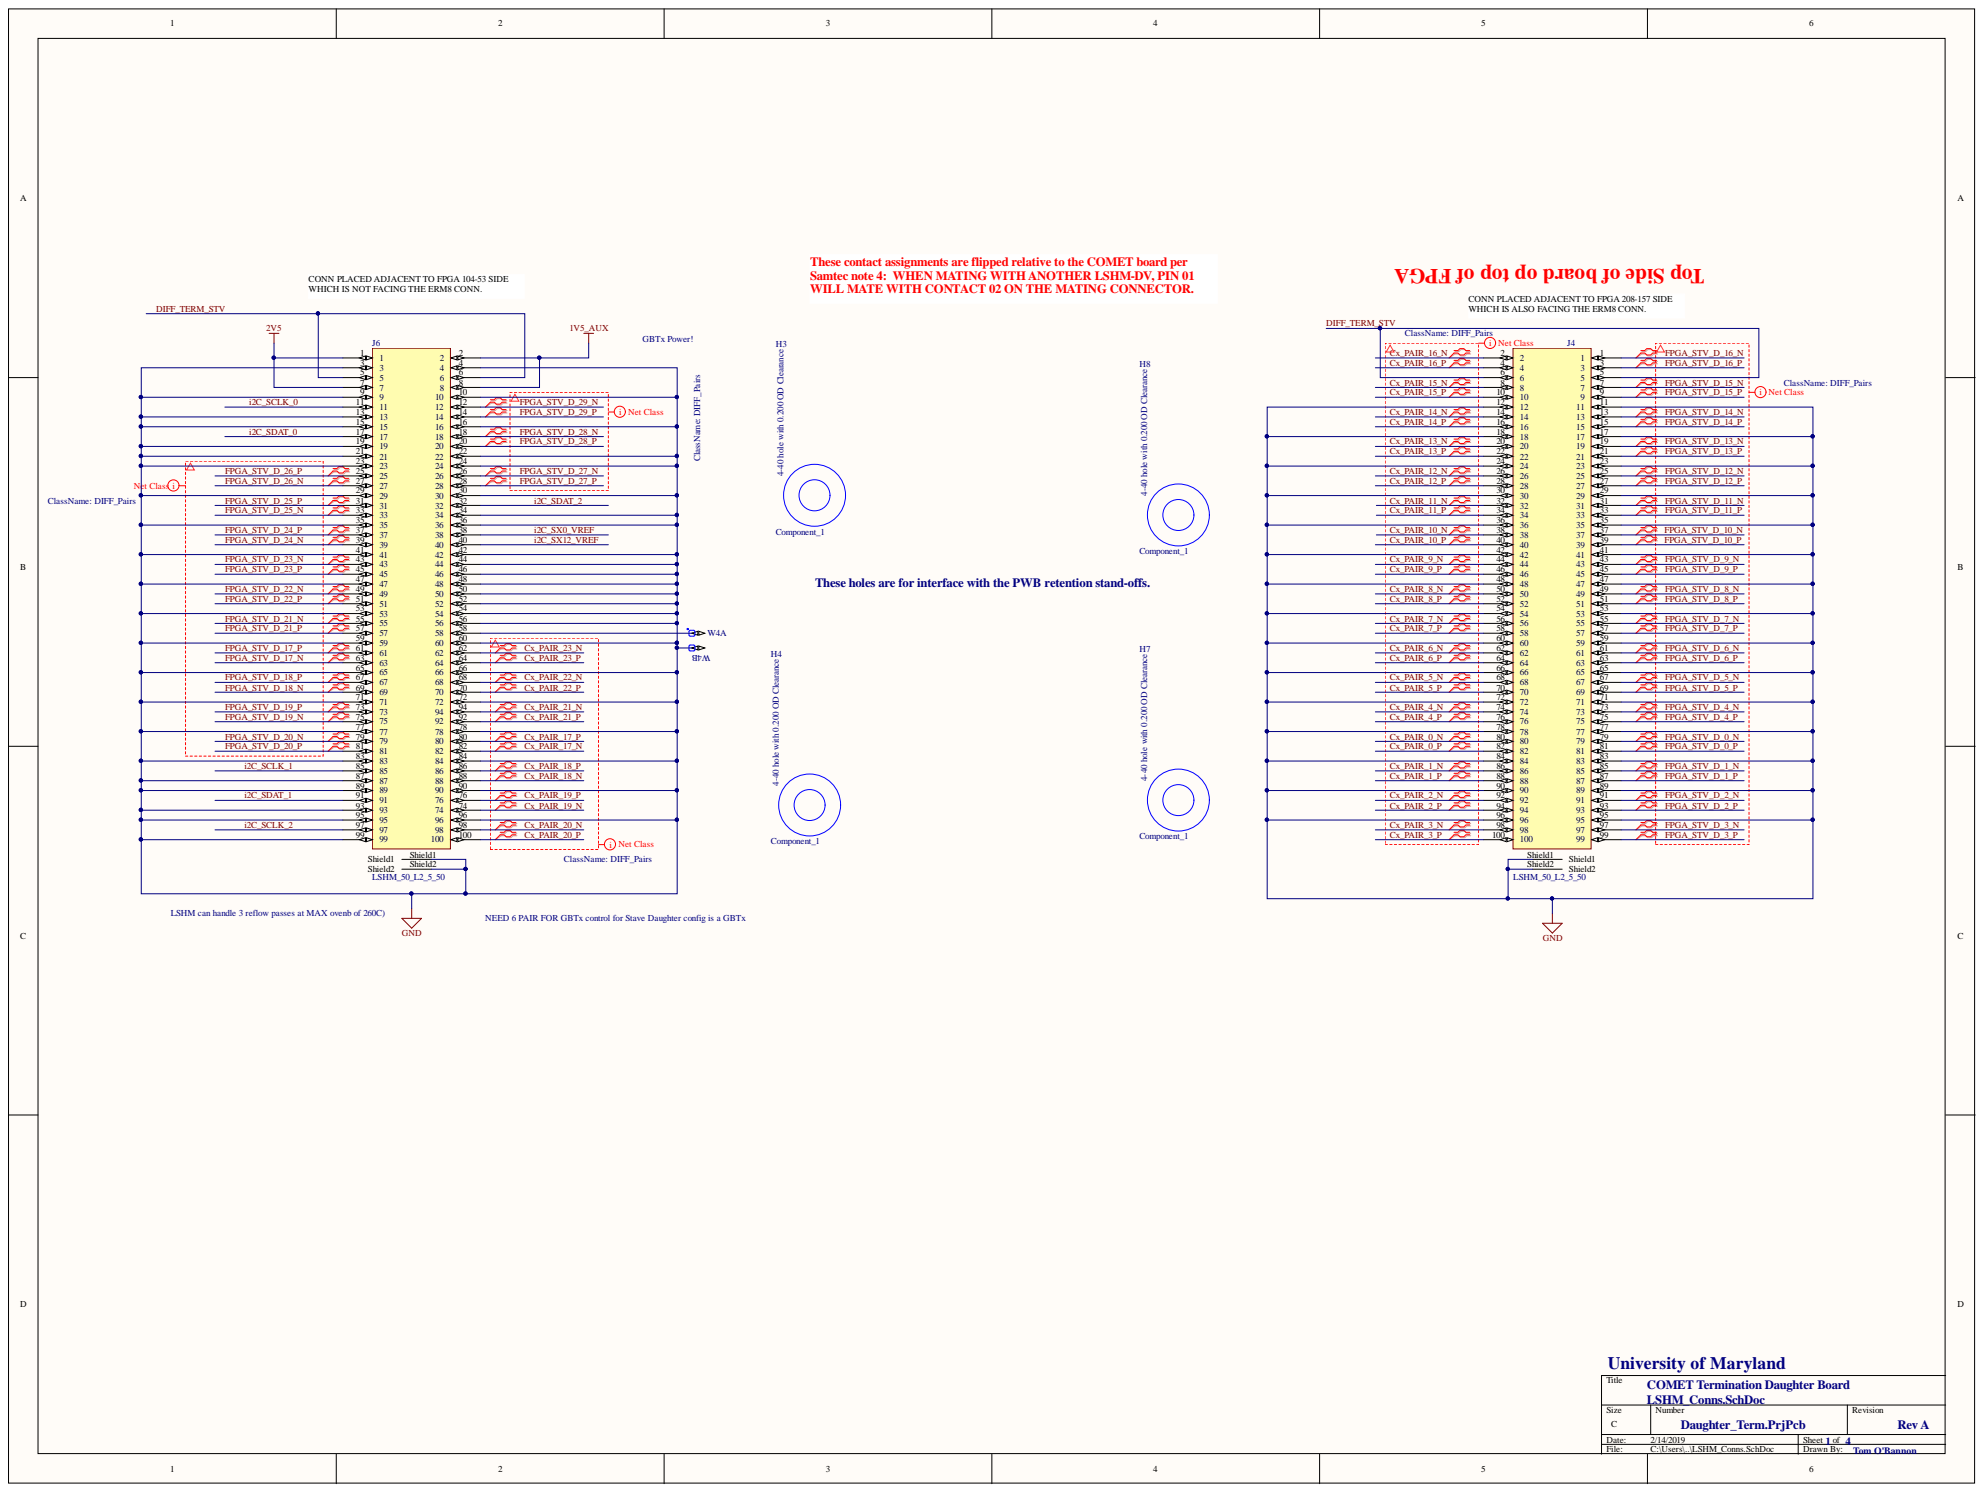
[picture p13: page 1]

e flip
nts
MATING WITH ANOTHER LS

4-40 hole with 0.200 OD Clearance H3

4-40 hole with 0.200 OD Clearance H8

4-40 hole with 0.200 OD Clearance H4

4-40 hole with 0.200 OD Clearance H7

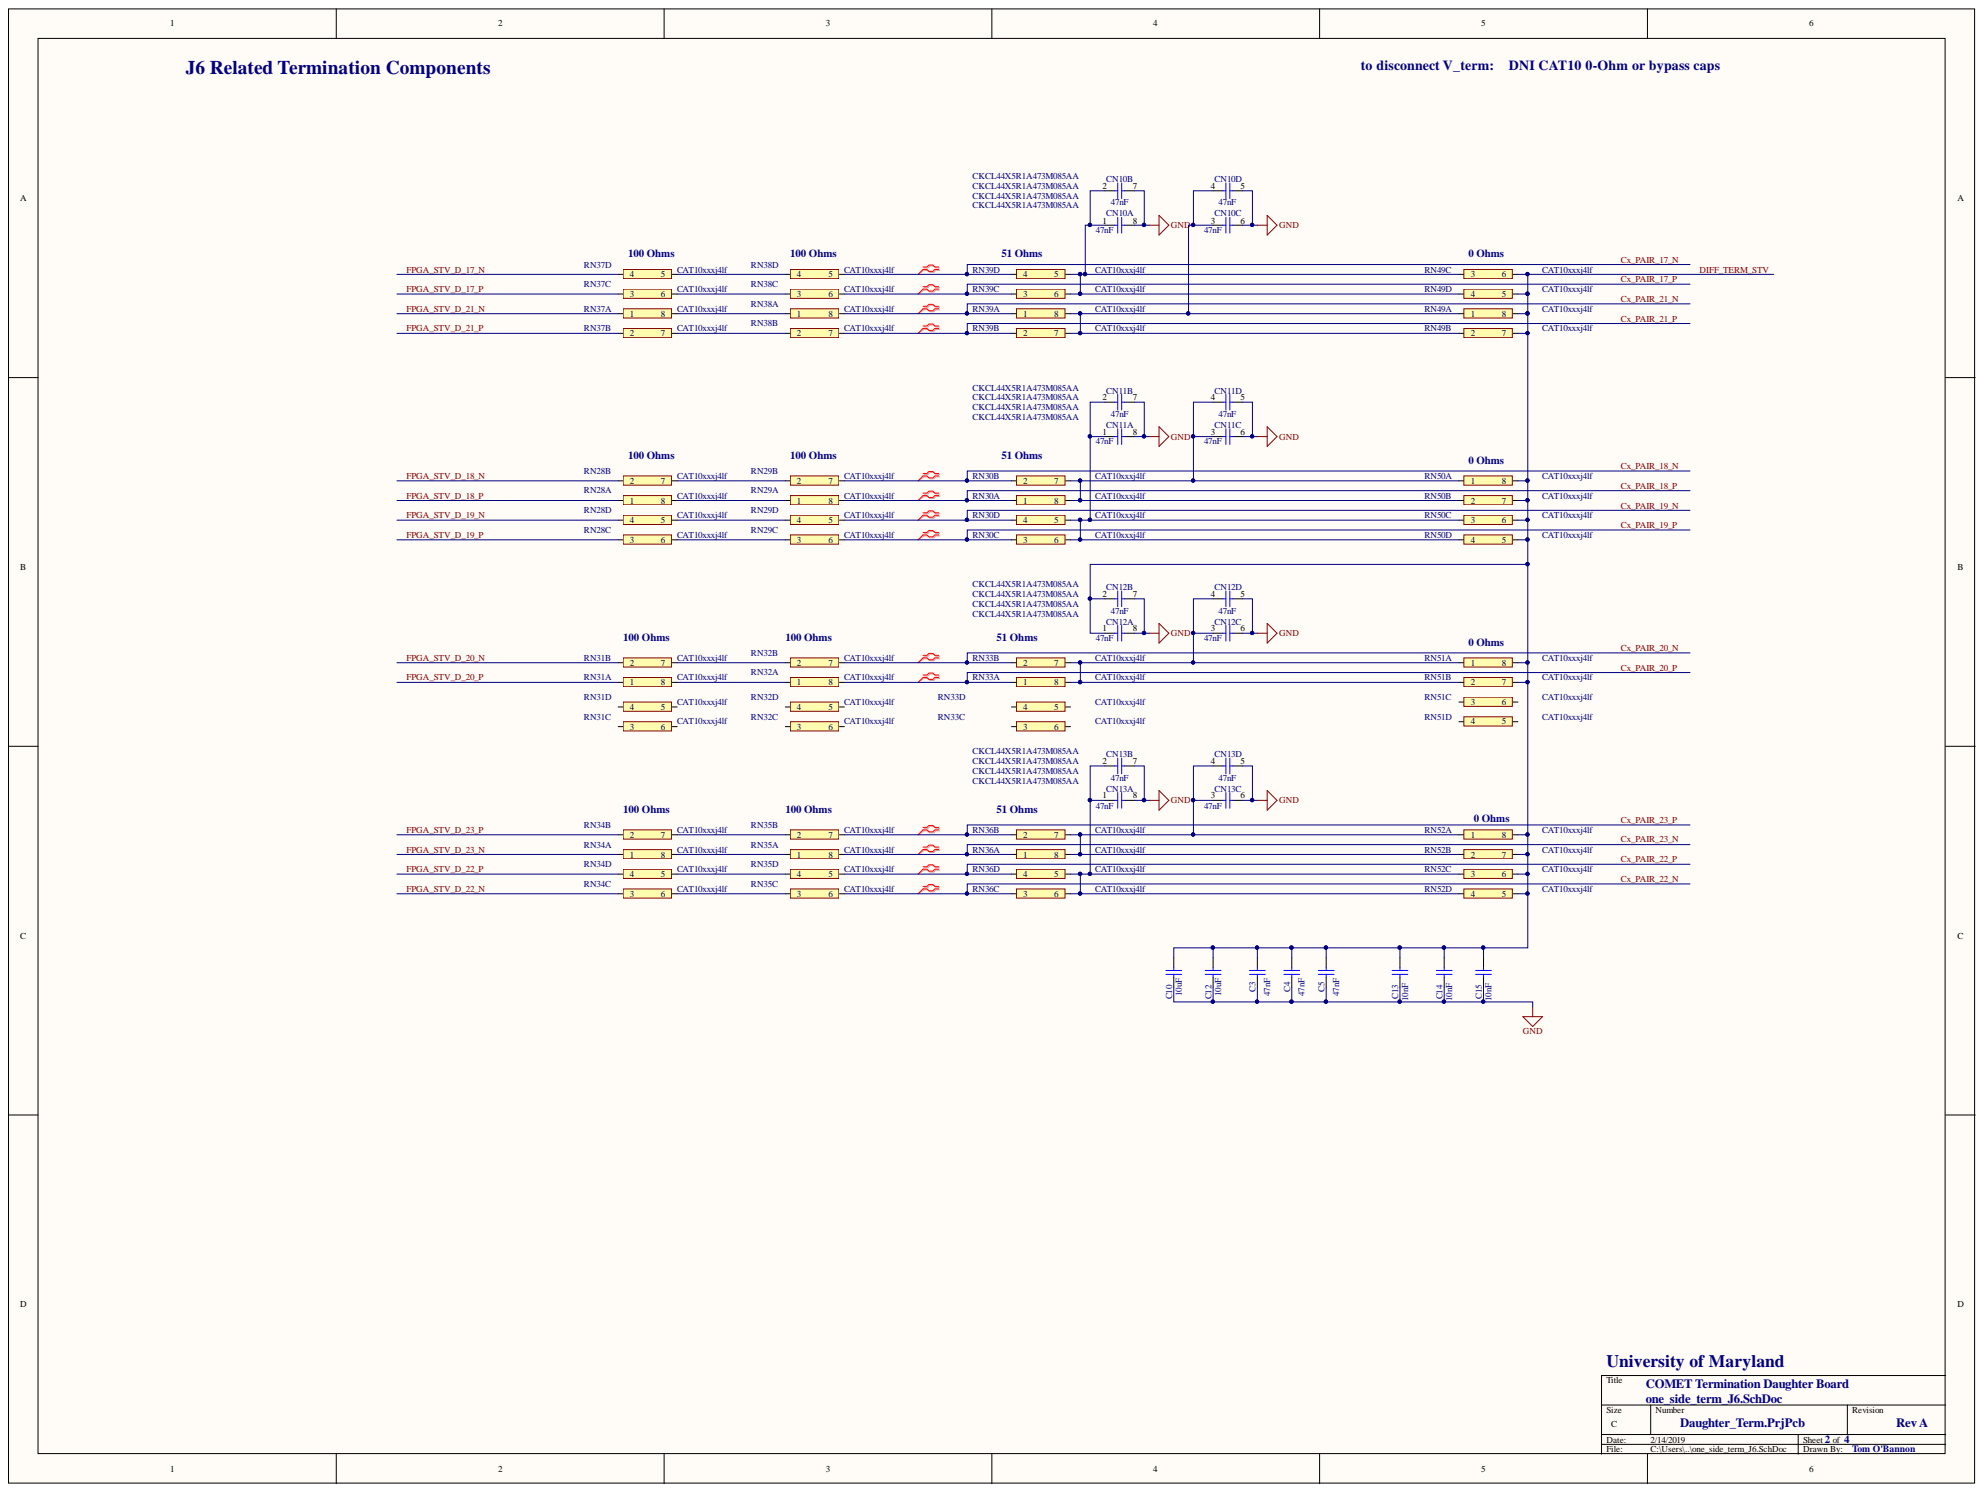
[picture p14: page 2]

COMET Termination Daughter Board
one_side_term_J6.SchDoc

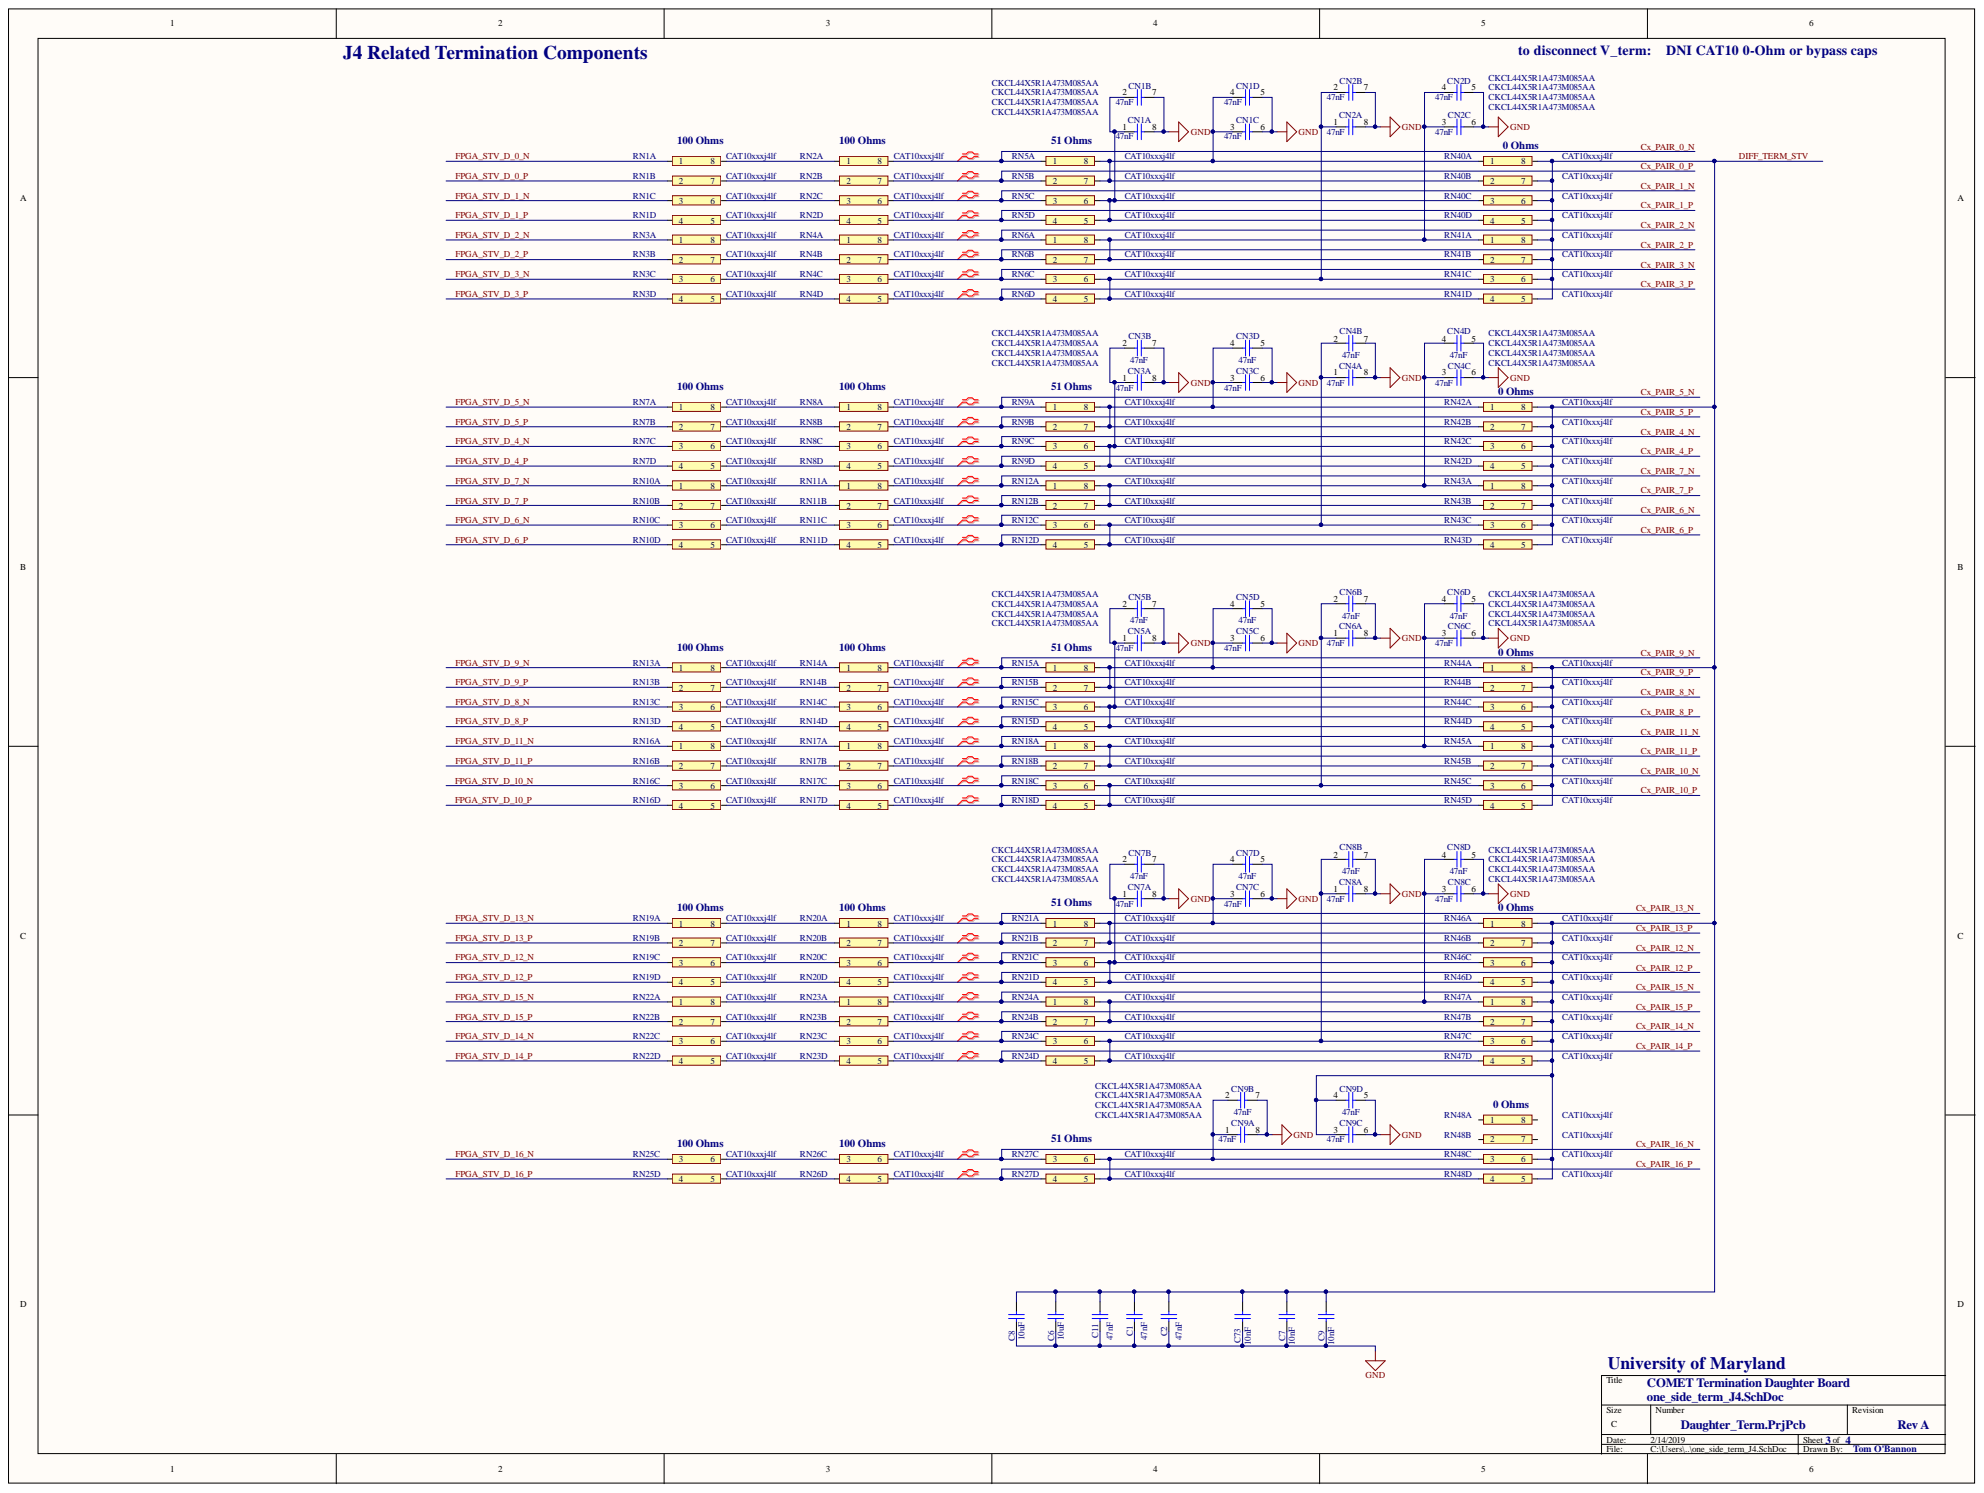
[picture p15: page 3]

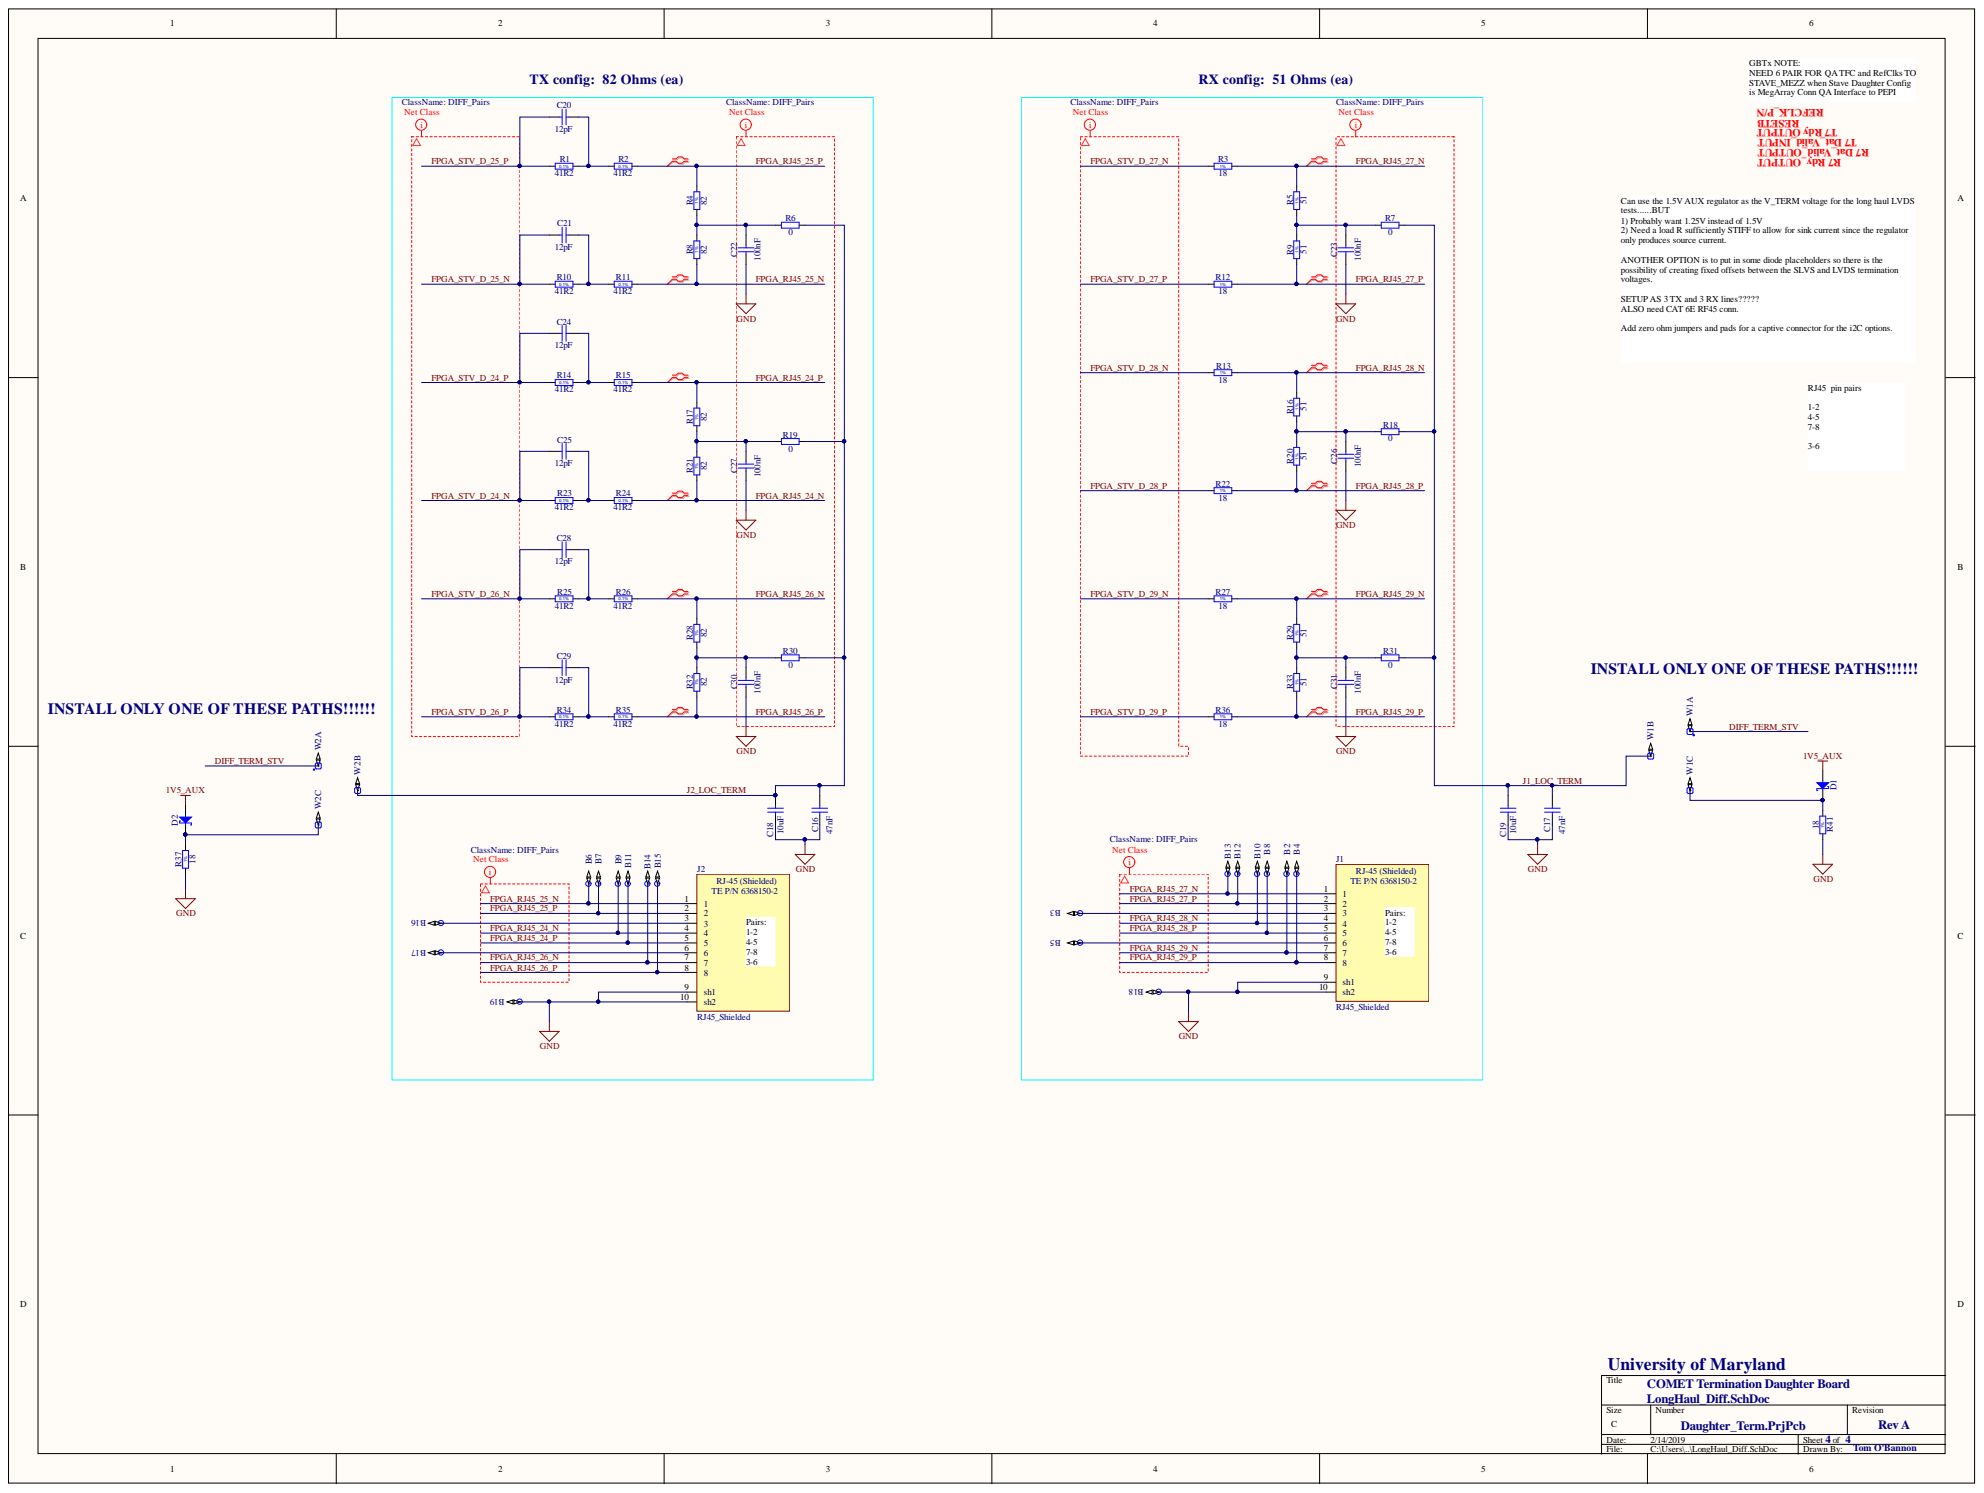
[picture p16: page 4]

aryland COMET Termination Dau

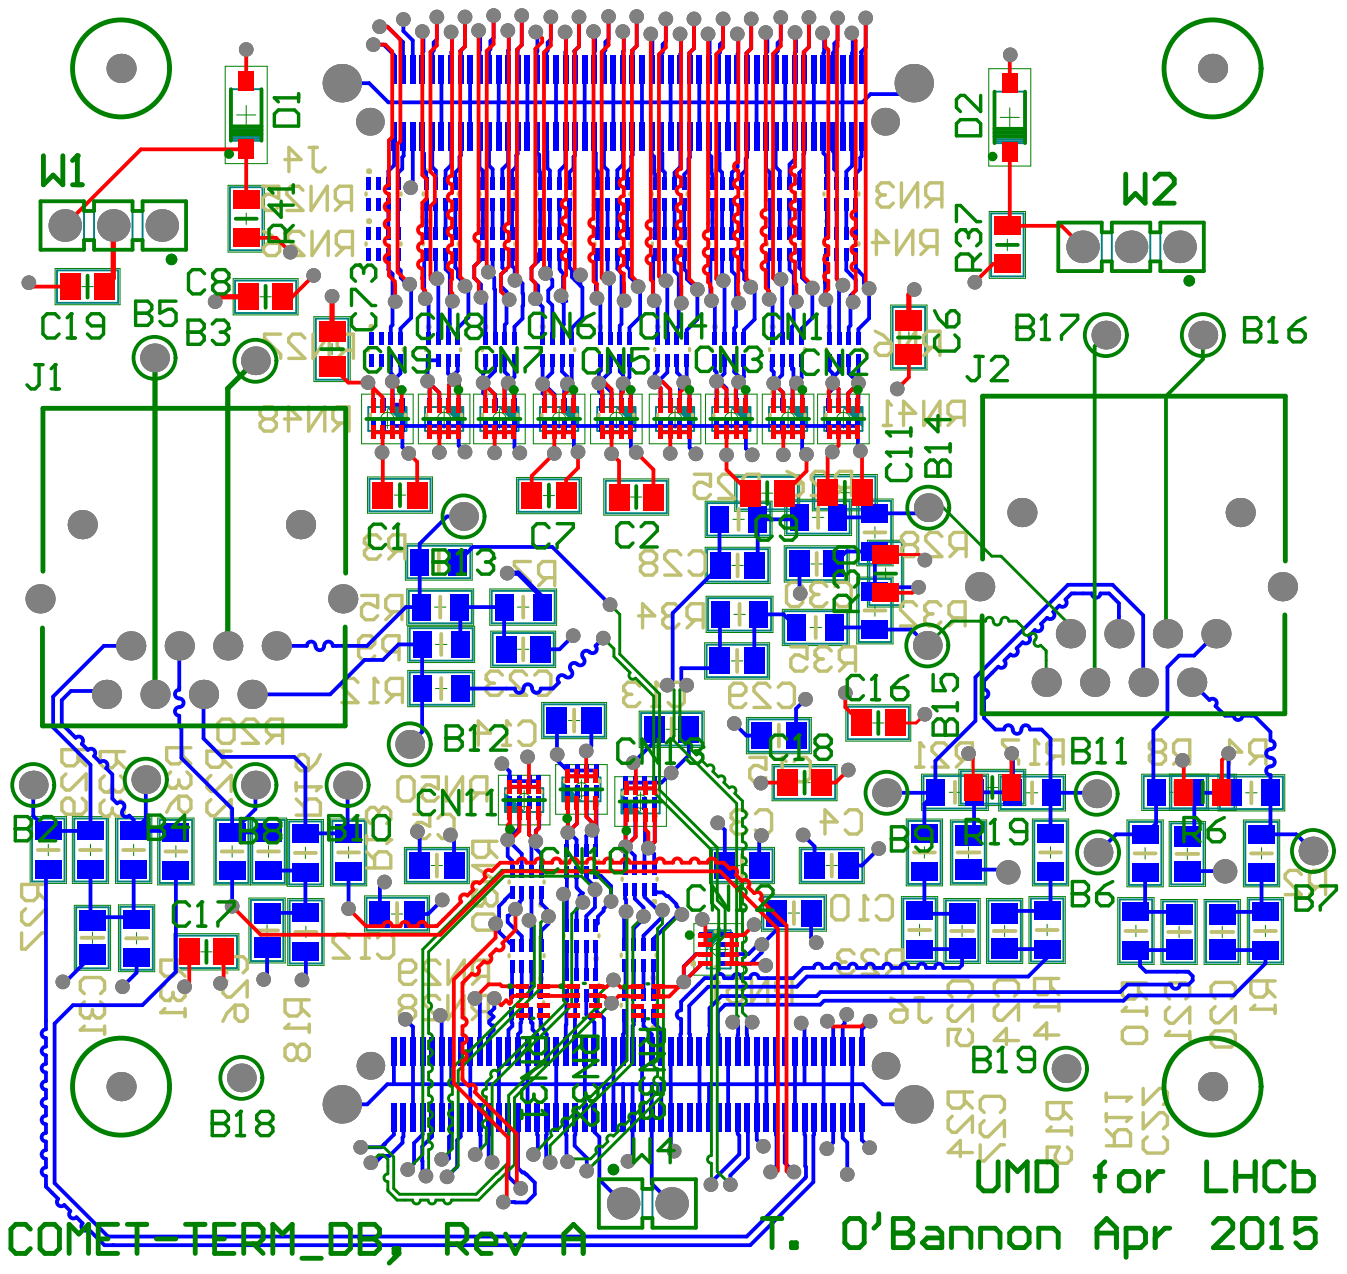
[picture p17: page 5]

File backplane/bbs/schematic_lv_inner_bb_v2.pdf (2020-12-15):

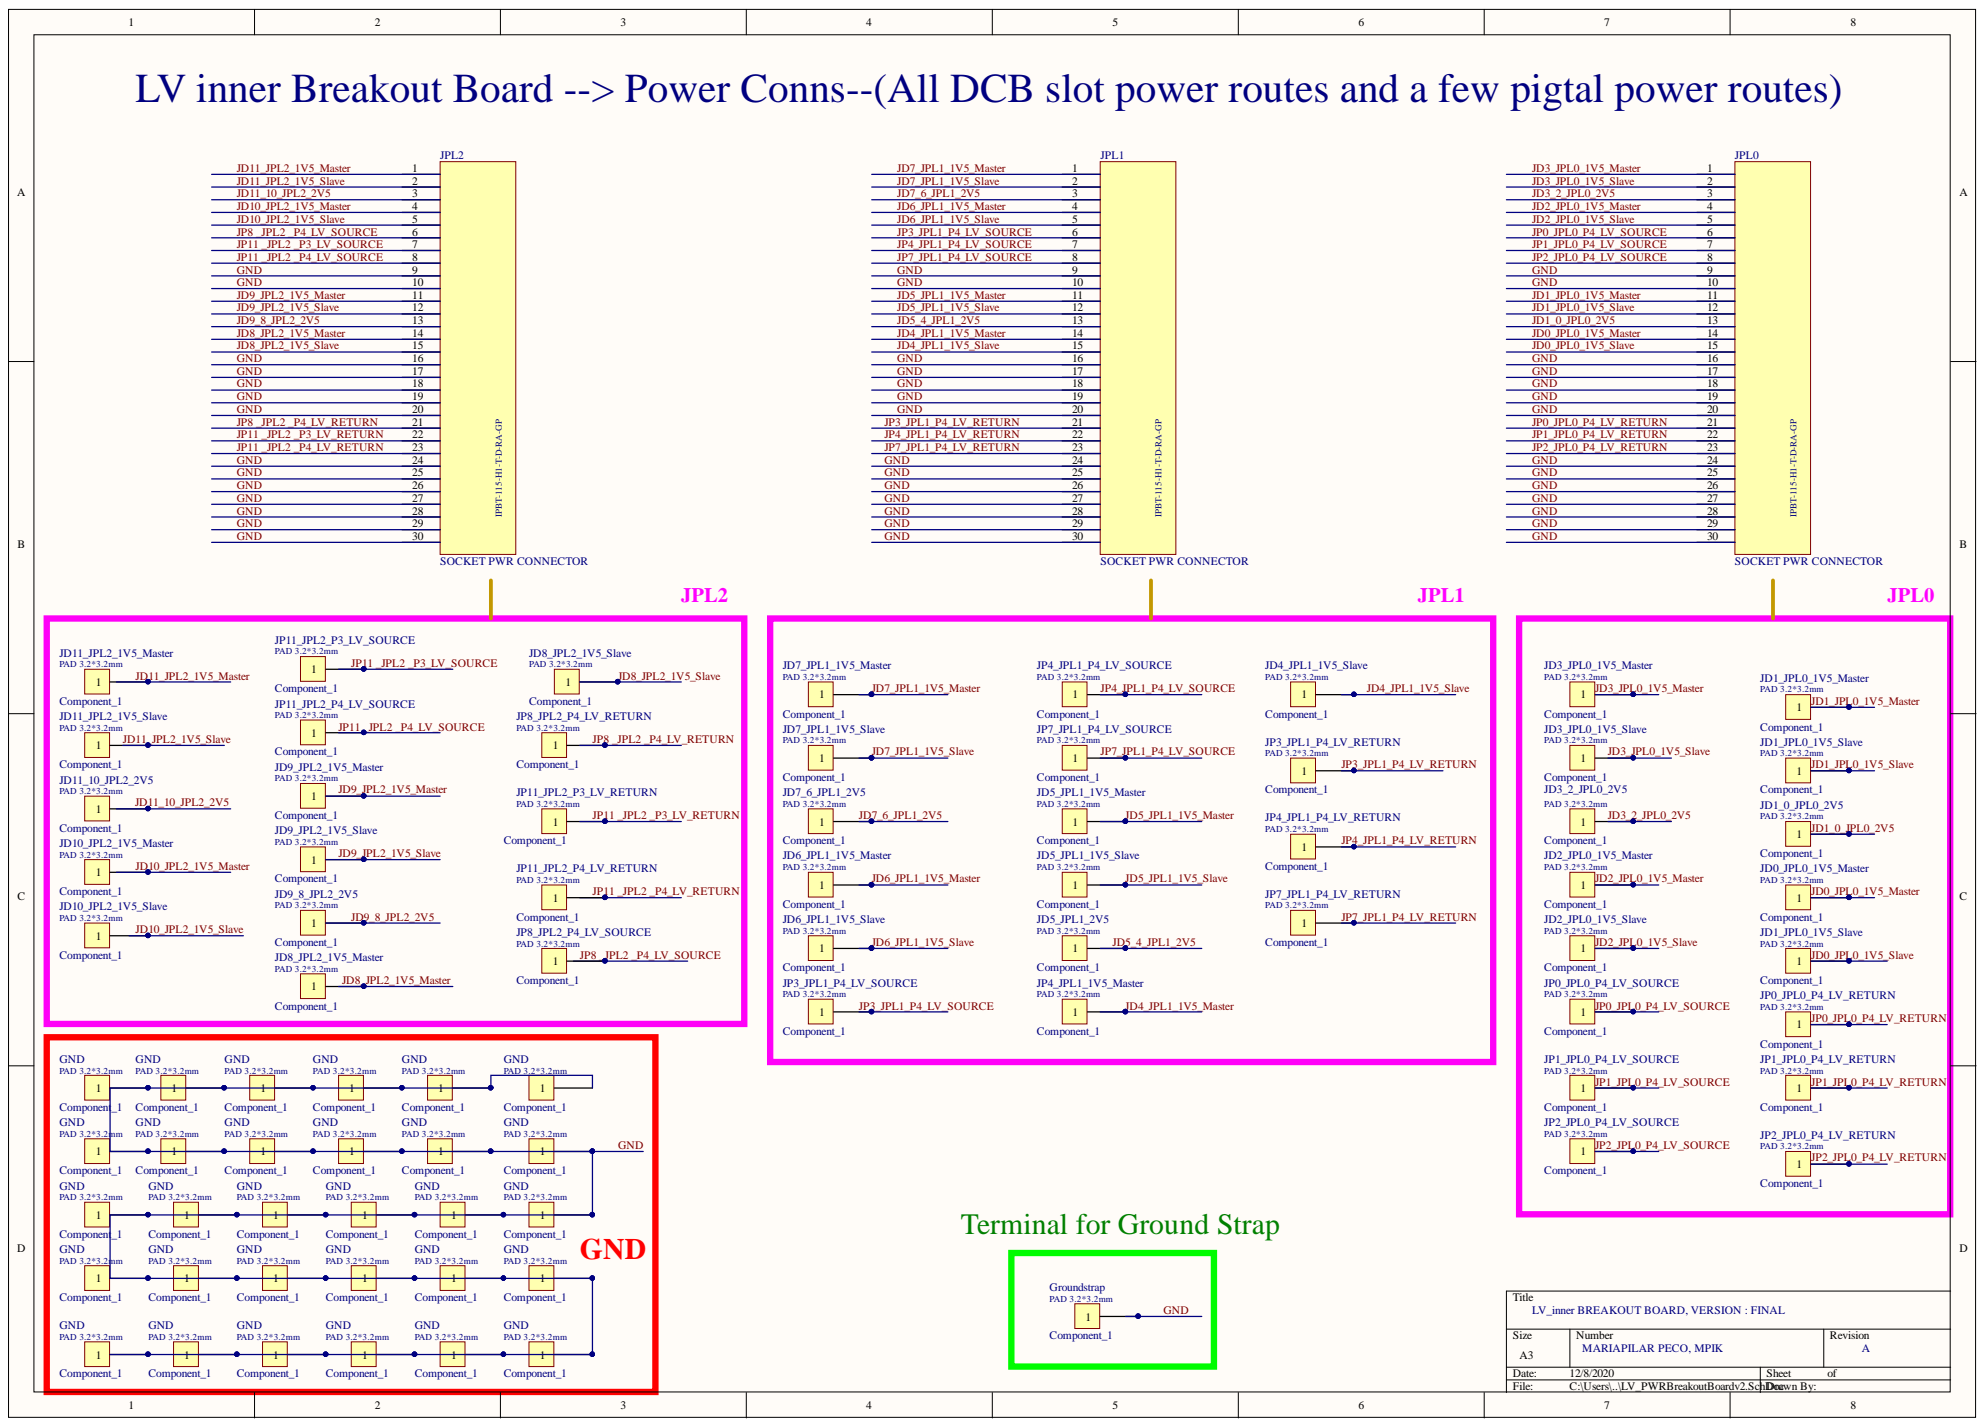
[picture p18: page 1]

LV inner Breakout Board --> Power Conns--(All DCB slot power routes and a few pigtal power routes)

Terminal for Ground Strap

Title
LV_inner BREAKOUT BOARD, VERSION : FINAL

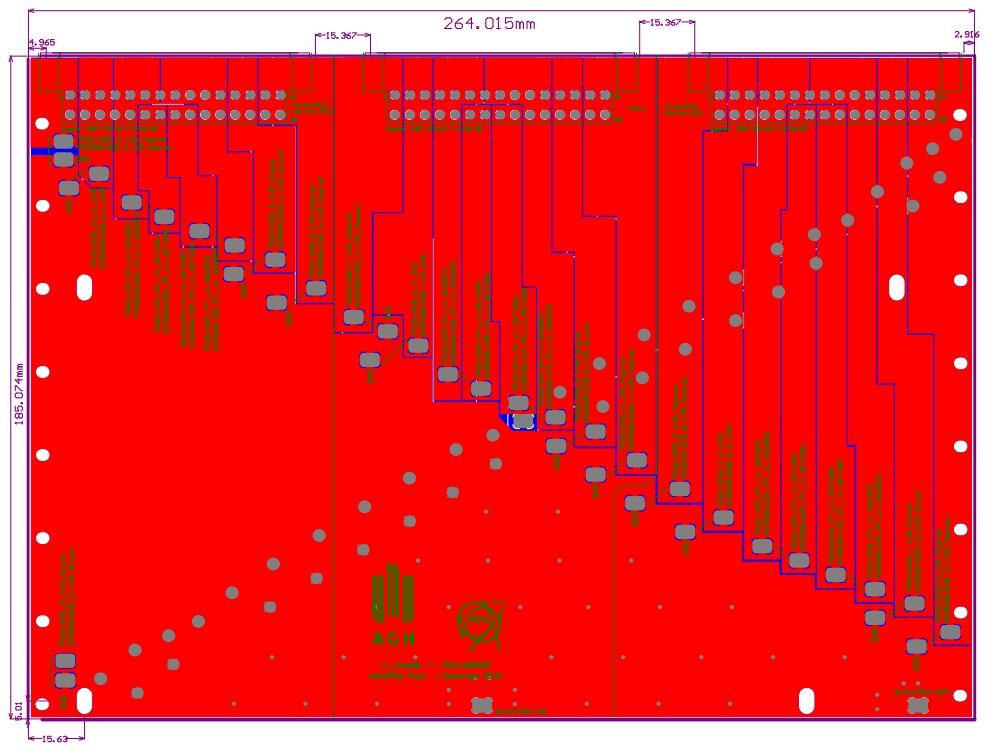
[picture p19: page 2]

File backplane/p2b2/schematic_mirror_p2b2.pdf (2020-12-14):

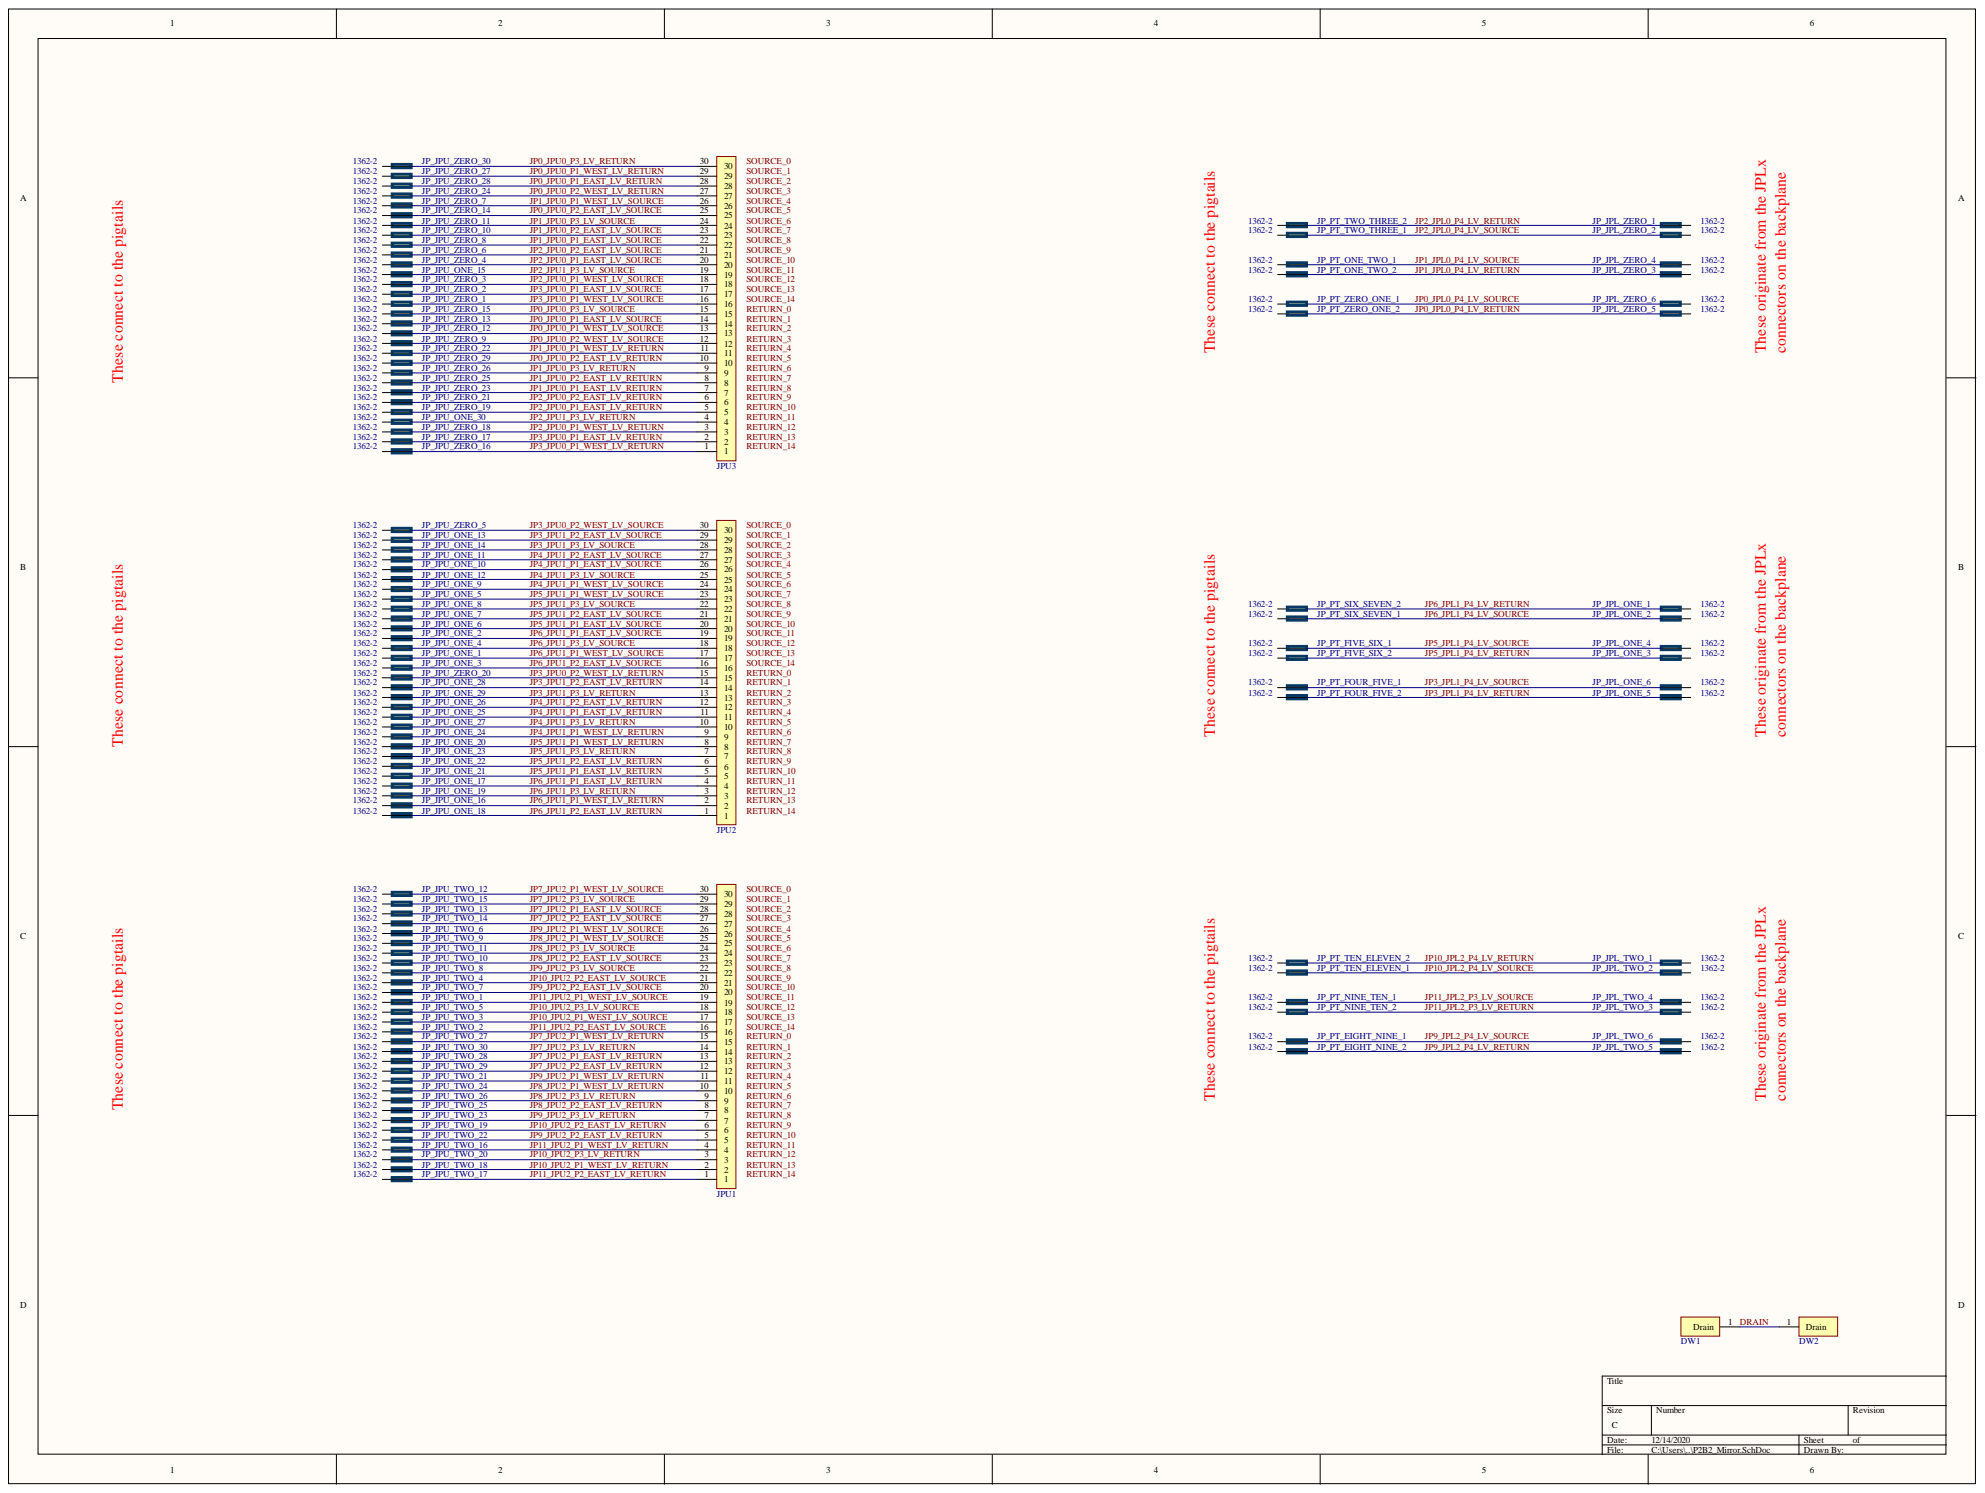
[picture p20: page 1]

These originate from the JPLx

These connect to the pigtails

connectors on the backplane


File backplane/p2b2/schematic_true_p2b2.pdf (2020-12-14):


These originate from the JPLx

These connect to the pigtails

connectors on the backplane


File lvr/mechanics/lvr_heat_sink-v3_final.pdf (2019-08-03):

TB v2.0 A1:Landscape; EQUIPMENT CODE; MASS 652 g; ISO 2768-mK; ISO 13715; MATERIAL; INITIAL STATE; FINAL STATE; Common zone; Detail A Scale: 4:1

0.1 | B
0.2 | B

All holes in table

0.05 | C
0.1 | C

All pockets (8x) are the same 21mm (x) by 26mm (y),
with 3mm radius in corners and they are 2mm deep.
See detail A.

Hole Dimension Table

All square stand-offs ("islands") (10x) are the same
Center of the square coincides with center of the
respective threaded hole.
Applies to holes 3 to 12 form hole dimension table.

Thread depth for all threaded holes is 6mm.

Material: Aluminium alloy 6082 - T6

11 | 172.8 | 51.62 | M2.5
12 | 172.8 | 183.32 | M2.5
13 | 223.49 | 5.78 | M2.5
14 | 225.78 | 229.22 | M2.5
15 | 56.8 | 33.23 | 8
16 | 56.8 | 68.8 | 8
17 | 56.8 | 160.05 | 8

ISO GPS STANDARDS

EUROPEAN ORGANIZATION FOR NUCLEAR RESEARCH

This drawing may not be used for commercial purposes without written authorisation

Ce dessin ne peut etre utilise a des fins commerciales sans autorisation ecrite

ORGANISATION EUROPEENNE POUR

LA RECHERCHE NUCLEAIRE

NOTE: UNLESS OTHERWISE MENTIONED, APPLICABLE ISO GPS STANDARDS ARE THOSE PRIOR TO 2010-08-01 REGARDLESS OF THE DRAWING DATE

DESIGNATION LVR Heat Sink | DESIGNED | M.GALKA | FORMAT A1

CHECKED

APPROVED
DESIGNED 2019-02-13

REFERENCES Doc No: ST1091384_02 | INDEX | LABEL NOT VALID FOR EXECUTION | QAC | SHEET 1/1

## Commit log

2019-02-14 Add COMET related schematics
2019-02-14 Add COMET schematic.
2019-02-14 Add DCB schematics.
2019-02-14 Update README to indicate that we will be providing schematics as well other UT-related testing boards.
2019-02-15 Add Path Finder schematic.
2019-02-23 Added backplane project after schematics sign off
2019-05-07 First full draft of True backplane project with gerbers
2019-05-08 Added Mirror backplane schematics
2019-05-17 True backplane gerbers with 3 assembly variants
2019-05-24 Added updated True backplane with 8 mill D2C and removed unused via pads
2019-05-31 Added True backplane with D2C 8 mills everywhere
2019-06-25 Added True backplane .dxf with keepout areas and top holes
2019-06-26 Added ODB++ of current Mirror backplane and LVR schematics
2019-08-07 Added project and gerbers for Custom Telemetry BB
2019-08-08 Added True backplane and P2B2 .step files
    [2019-07-15_P2B2.step]
2019-08-14 Added True backplane fab with paste pads on DCB connectors
2019-08-14 Removed gerbers from true backplane fab
2019-08-20 Add new fabrication files, including drill file
2019-09-04 Added gerbers for True backplane
2019-09-04 Added Aug 14 True backplane gerbers
2019-09-05 Create 2019-09-05_lvr_project.zip
    Reuploaded with fixed LVR BOM
2019-09-16 Add provisional final DCB design schematics
2019-10-07 Added TRUE-type custom telemetry BB for testing
    Telemetry BB connector spacing was inherited from pathfinder, but is different in TRUE-type production BP (!!!)
    This project has a modified custom telemetry board layout that should be compatible with the production BP
2019-10-10 BB (true) with 26mil holes, 5mil trace/space
2019-10-14 Added STEP files for mirror P2B2 and combined backplane/P2B2
    [2019-10-10_mirror_P2B2.step]
2019-10-16 On behave of Zishuo: Add updated true + mirror projects with Fab+Assembly+BOM.
2019-10-24 Added stl and x3g files for all separator pieces
2019-10-24 Added Mirror P2B2 gerbers
2019-10-24 Zishuo: Add fab and bom.
2019-10-30 Updated stl and x3g files with new bottom piece
2019-10-31 Updated True CustomTelemetryBB fab+assembly.zip
    Fixed the routing bug for the RESET_2 trace going to BackplaneGND
2019-10-31 Added STEP files for true P2B2 and P2B2/BP
    [2019-10-28_true_P2B2.step]
2019-11-01 The step files should not be executable.
    [2019-10-10_mirror_P2B2.step, 2019-10-28_true_P2B2.step]
2019-11-18 Compatable with mirror and added through-holes
2019-11-22 Add True and Mirror backplane schematics.
2019-11-25 .dxf and .stp versions of spacers
2019-12-02 Split models to fit printer
2019-12-09 Simplified and re-fit top spacer
2019-12-13 Added true P2B2 v2 gerbers, and updated alpha BOM for true backplane
2019-12-18 Replace Mirror backplane schematics with latest numbering scheme
2019-12-30 Added latest DCB projects, gerbers, and schematics
    [2019-09-30_dcb_bom.xls, 2019-10-02_dcb_opt_mezz_bom.xls]
2019-12-30 Reorganized backplane files
    [2018-10-24_pathfinder_backplane_bom.xlsx, 2019-12-13_true_backplane_bom_alpha.xlsx, 2019-12-13_true_backplane_bom_beta.xlsx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]
2020-01-06 Re-organized LVR files
    [2019-09-05_lvr_bom.xlsx, 2019-10-09_ccm_bom_12A.xls, 2019-10-09_ccm_bom_12M.xls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]
2020-01-06 Grouped CCM BOMs
    [2019-10-09_ccm_bom_12A.xls, 2019-10-09_ccm_bom_12M.xls, 2019-10-09_ccm_bom_12S.xls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]
2020-01-16 Added Pathfinder BOM
    [BOM_PathFinder_Oct18_2018_for_Sierra.xlsx]
2020-01-17 Renamed backplane variants
    [2019-12-13_true_backplane_bom_d.xlsx, 2019-12-13_true_backplane_bom_f.xlsx, 2019-12-13_true_backplane_bom_p.xlsx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]
2020-01-17 Added final desing of spacers
2020-11-30 Updated failsafe resistor in LVR project, schematics
2020-12-14 Update P2B2 schematics to always include a layout.
2020-12-15 Add LV Inner BB v2 schematic.
